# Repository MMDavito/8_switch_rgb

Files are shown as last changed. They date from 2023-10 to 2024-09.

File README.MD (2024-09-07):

# Table of contents
- [Table of contents](#table-of-contents)
- [1.1 Introduction:](#11-introduction)
- [1.2 Demonstration:](#12-demonstration)
  - [1.2.1 English:](#121-english)
  - [1.2.1 Swedish:](#121-swedish)
- [2 Design and process:](#2-design-and-process)
  - [2.1 Arduino](#21-arduino)
  - [2.2 KiCad](#22-kicad)
    - [2.2.1 Schematics and details:](#221-schematics-and-details)
      - [2.2.1.1 PCB rev0](#2211-pcb-rev0)
      - [2.2.1.2 PCB rev1](#2212-pcb-rev1)
    - [2.2.2 Custom Footprint SPDT-Switch:](#222-custom-footprint-spdt-switch)
    - [2.2.3 Custom Footprint 7-segment Display:](#223-custom-footprint-7-segment-display)
  - [2.3 FreeCAD](#23-freecad)
- [3 Assembly:](#3-assembly)
  - [3.1 Assembly of frame/stand:](#31-assembly-of-framestand)
  - [3.2 Assembly/soldering of the PCB](#32-assemblysoldering-of-the-pcb)
    - [3.2.1 Resistors required:](#321-resistors-required)
    - [3.2.2 Order of assembly:](#322-order-of-assembly)
- [4 Programming and bootloading:](#4-programming-and-bootloading)
  - [4.1 Bootloading:](#41-bootloading)
  - [4.2 Programming:](#42-programming)
  - [4.3 Programming the MCU for PCB Revision 1:](#43-programming-the-mcu-for-pcb-revision-1)

________________

# 1.1 Introduction:
This project was created to teach my niece the wonders of electricity and programming.
Here is a video trying to give and project overview and explain the process that made me go from 64 bit memory board to a "space-machine":<br>
8 Switch RGB project overview and presentation (https://www.youtube.com/watch?v=f2jGDhYTRMw)

# 1.2 Demonstration: 
## 1.2.1 English:
Using Revision 0:<br>
English demonstration revision 0 (https://www.youtube.com/watch?v=hgyK7DbGRng)

## 1.2.1 Swedish:
Better quality than the english one, using PCB revision 1:
Swedish demonstration revision 1 (https://www.youtube.com/watch?v=zpn5mNTmlIY)

___________
# 2 Design and process:
## 2.1 Arduino
No real design was put in here since the issues needing solving where clearly limited and modular in its nature, the process I choose was to solve issues limited in scope and carry out experiments with components in as modular of a manner as possible.
This is how the original prototype described in the video above ended up containing 3 ATmega-328's.

This approach did however result in many .ino files and duplicate code. The decision I made was to keep all of them; this will allow me to return 5-10 years from now and realize my process of thinking and working has changed and how, maybe I will write a book or blog-post about it. 

## 2.2 KiCad
### 2.2.1 Schematics and details:
The only major differences between the two schematics are that I have a filter on the data and clock-lines in revision 1. I also relabeled the decimal-displays from order "dec-2" to "dec-0" starting from upper left corner in revision 0, to the reversed (and ISO-standard) way of counting/indexing from 0 in the upper left corner.

I also left-out the fuse and some other things in order to conserve space.
#### 2.2.1.1 PCB rev0
Will not publish Gerbers because this version should never ever be built or produced, as can be viewed in this 30 second clip:
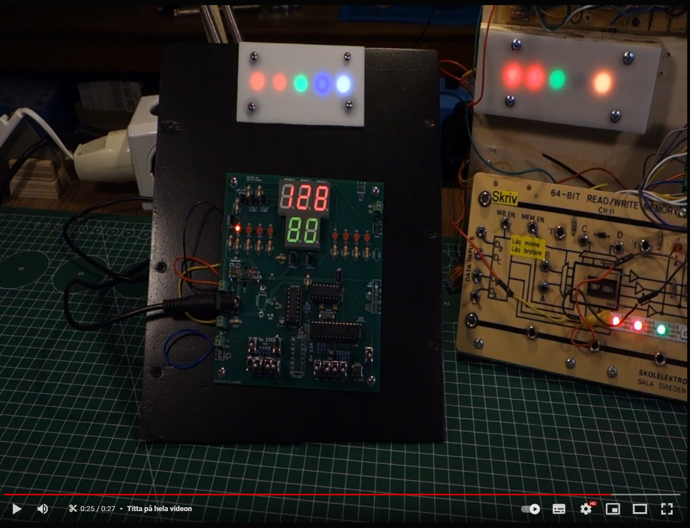
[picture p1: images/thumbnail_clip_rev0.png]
Clip showing the horror of revision 0 (https://www.youtube.com/clip/UgkxvULYqhLVdSH0bBzPMFzRGHbVHcaSfia2)

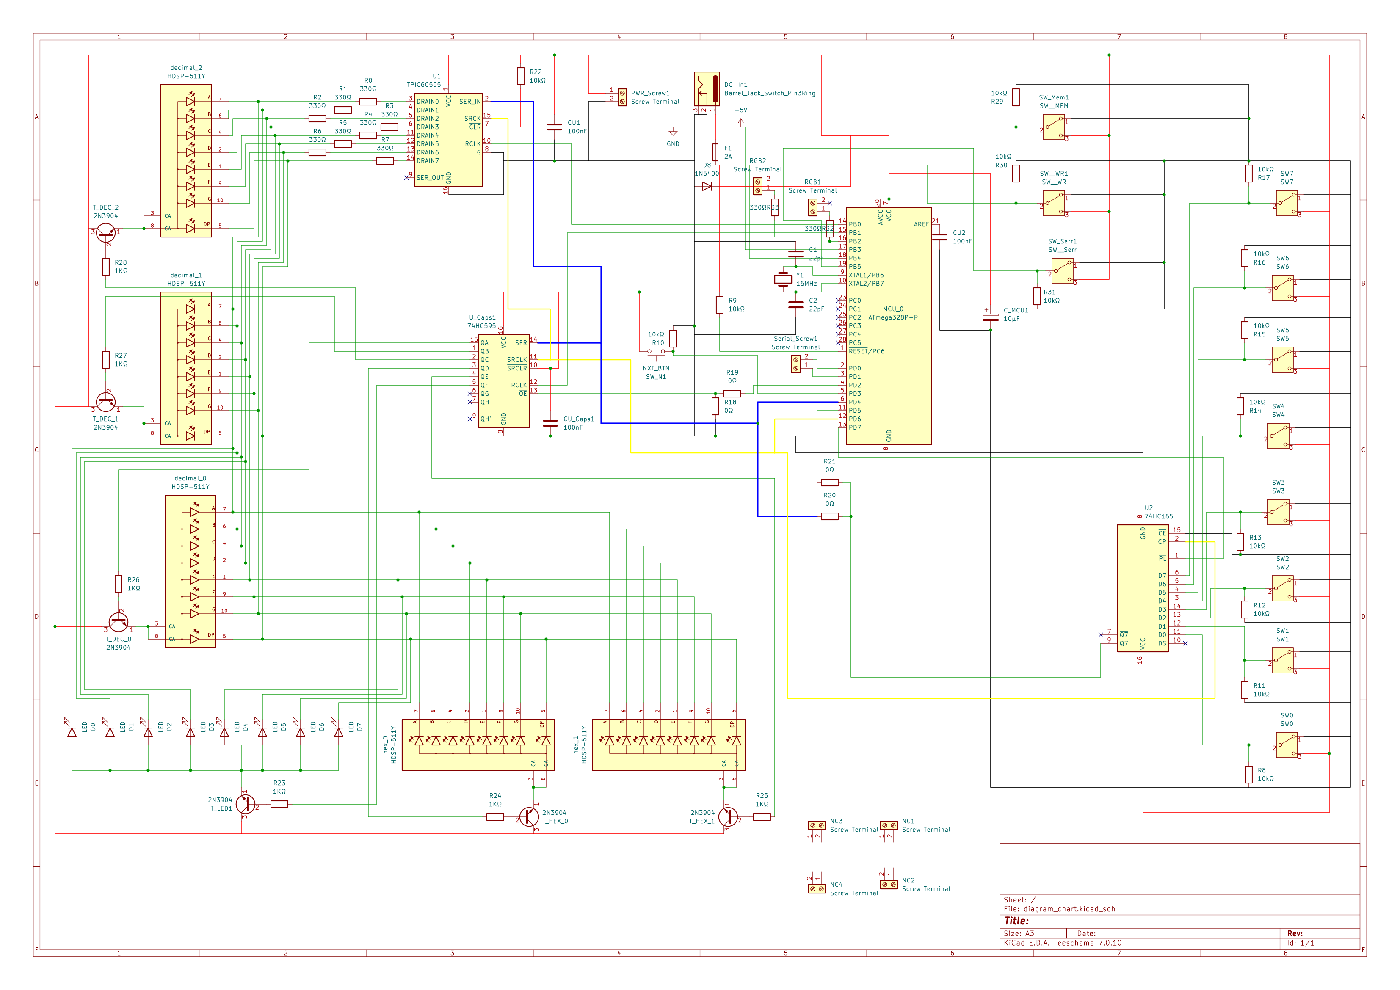
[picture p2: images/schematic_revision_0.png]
PCB revision 0 Schematic

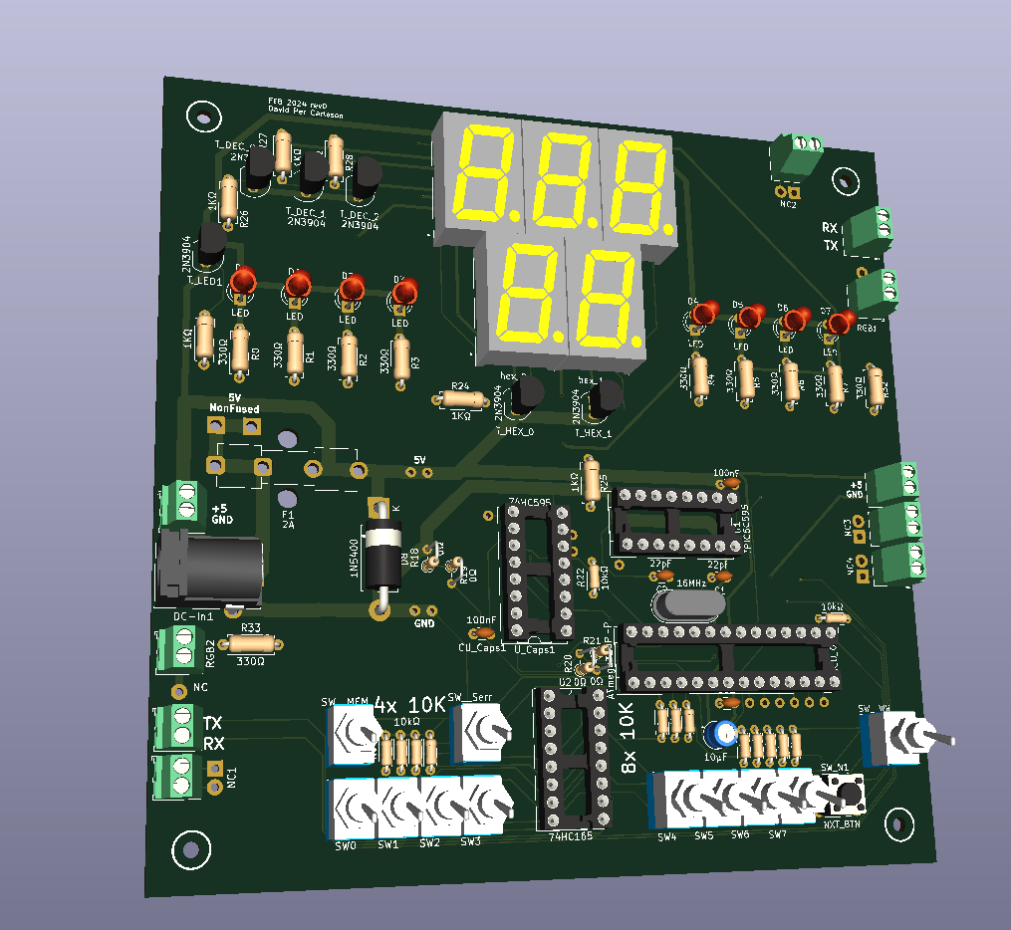
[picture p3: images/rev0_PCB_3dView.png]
PCB revision 0 PCB 3D view


#### 2.2.1.2 PCB rev1
Gerbers available for order in this directory:
https://github.com/MMDavito/8_switch_rgb/tree/master/KiCad/8_switch_rgb_pcb_revision_1/gerber_to_order
PCB revision 1 Schematic
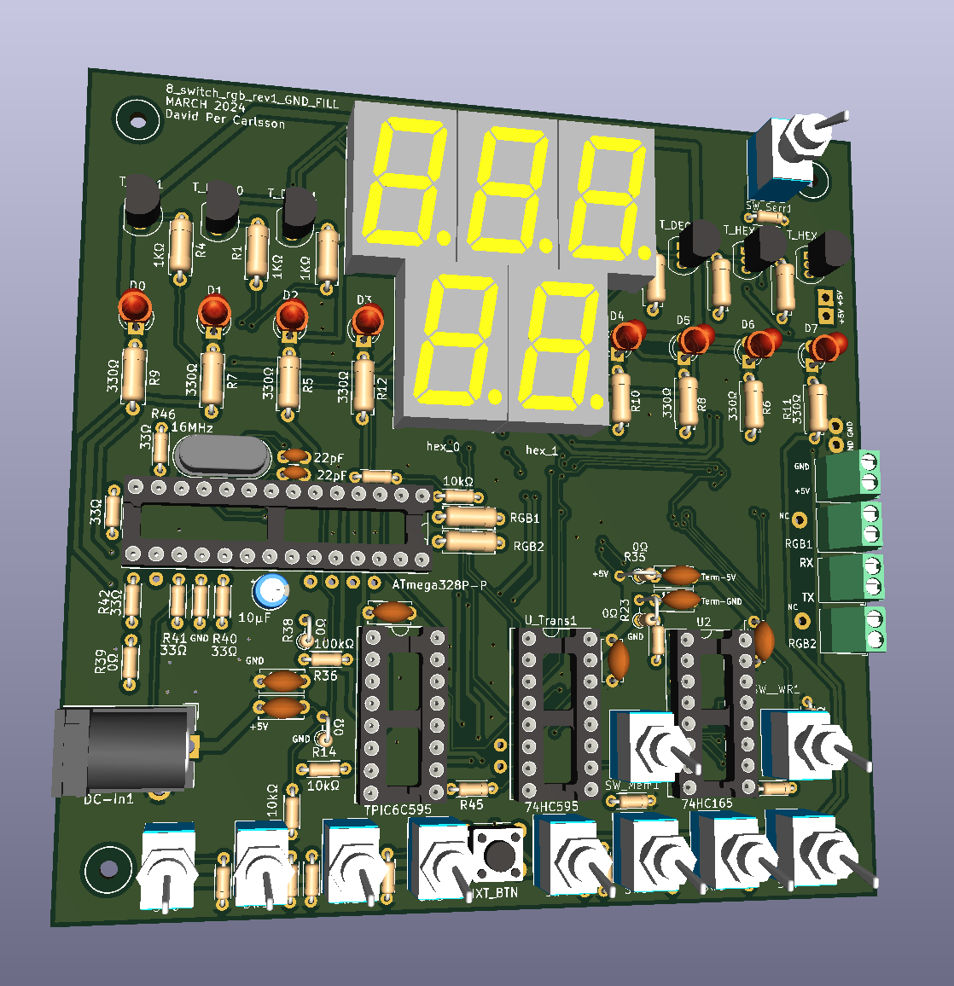
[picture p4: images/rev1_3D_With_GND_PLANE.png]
PCB revision 1 PCB 3D view

### 2.2.2 Custom Footprint SPDT-Switch:
The SPDT switch was purchased from digikey: https://www.digikey.se/sv/products/detail/adam-tech/SW-T3-2B-A-A3-S1/15284416 <br>
And later electrokit: https://www.electrokit.com/vippomkopplare-sub-miniatyr-1-pol-on-on-lodoron-smts-102

These had to be changed, since the footprints I found where for the larger 6-Amp switch. If I where to refactor the PCB I would probably make the soldering-pads 20% larger for this footprint, or even more if DRC/Design-Rules-Checker would allow it.
The custom footprint can be found here: https://github.com/MMDavito/8_switch_rgb/tree/master/KiCad/resources/Switch_Custom.pretty
### 2.2.3 Custom Footprint 7-segment Display:
The display used was a 14mm CA display purchased in RED here: https://www.electrokit.com/en/led-display-7-seg-14mm-superrod-ca <br>
And green from here: https://www.electrokit.com/en/led-display-7-seg-14mm-gron-ca

The schematics, PCB and footprint label it as a HDSP-511, which is incorrect, buying HDSP-511 would lead to buying a display too tall and wide to fit.
The edited footprint and 3D .step file can be found here:
https://github.com/MMDavito/8_switch_rgb/tree/master/KiCad/resources/HDSP-511Y
## 2.3 FreeCAD
What started as a means to an end of making it simpler to mount the PCB to a piece of plywood ended up resulting in 4 different design for holders and 3-5 different tools for making assembly simpler.

This process and designs are detailed in this readme:
https://github.com/MMDavito/8_switch_rgb/tree/master/FreeCad/README.MD
____________
# 3 Assembly:
## 3.1 Assembly of frame/stand:
More clear information and details about the 3d-printed parts found in the following video can be found in [this readme](./FreeCad/README.MD), section [3.3](./FreeCad/README.MD#33-template-to-mark-drill-holes) and [3.4](./FreeCad/README.MD#34-led-matrix-holder).<br>
Assembling stand to hold the PCB (https://youtu.be/ce8ECqhq-No)

## 3.2 Assembly/soldering of the PCB
Assembling and soldering the PCB (https://youtu.be/1DfmUe_ZbE0)

### 3.2.1 Resistors required:
__1/8 watt resistors:__
* 10kΩ * 14
* 33Ω * 8
  
__1/4 watt resistors:__
* 330Ω * 2
* 220Ω * 8
* 1kΩ * 6

### 3.2.2 Order of assembly:
1. Small resistors (1/8 watt).
2. Big resistors (1/4 watt).
3. 3mm LED:s.
4. Transistors.
5. DIL-holders.
6. Toggle switches.
7. 7-segment displays.
8. DC-plug & screw-terminals.
9. Push-button, crystal & capacitors.
_____________
# 4 Programming and bootloading:
I used this library to allow me to install bootloader and program the ATmega https://github.com/MCUdude/MiniCore
## 4.1 Bootloading:
To get the ATmega328 become programmable one needs to install a bootloader to it:<br><br>
Here is the instruction I used: https://www.instructables.com/How-to-Burn-the-Arduino-BootLoader-on-to-a-AtMega3/

Here is a alternative version: https://www.instructables.com/Burning-the-Bootloader-on-ATMega328-using-Arduino-/

In future I might adjust the board I have made from a prototype-board or order a PCB that allow me to not need a arduino UNO connected with dupont-wires to install the bootloader to the ATmega-328.

## 4.2 Programming:
Somehow I managed to program the board using diagrams and information found on this page:
https://www.instructables.com/USB-to-Serial-TTL-Adapter-to-Program-ATmega328p/

And this video: 
https://youtu.be/tiETAwkxnmw?si=Nhqw3l6RTYwrkvaB

Skimming through above links I realize that neither really shows my process of programming the MCUs, and I should probably order a PCB and create a project to detail this.

Until I find the time for creating that PCB I here bellow attach a picture comparing the breadboard vs with the soldered prototype one.

I later attached the prototype-board to a piece of plywood to make it even more robust.
Programmer breadboard vs prototype-board

## 4.3 Programming the MCU for PCB Revision 1:
Using above instructions, load this sketch onto the MCU:
https://github.com/MMDavito/8_switch_rgb/blob/master/troubleshooting_and_revision_1/2024-03-07_8_switch_rgb_pcb_rev1/8_switch_rgb_rev_1_master_control/8_switch_rgb_r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

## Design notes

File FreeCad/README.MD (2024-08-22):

# Table of contents:
- [Table of contents:](#table-of-contents)
- [1 Introduction:](#1-introduction)
- [2 Holders:](#2-holders)
  - [2.1 The legacy from pcb revision 0:](#21-the-legacy-from-pcb-revision-0)
  - [2.2 The final version for pcb revision 1](#22-the-final-version-for-pcb-revision-1)
  - [2.3 The holder to display the failings of revision 0:](#23-the-holder-to-display-the-failings-of-revision-0)
- [3 Assembly Tools:](#3-assembly-tools)
  - [3.1 Mounting Frame:](#31-mounting-frame)
  - [3.2 Resistor Lead Bender:](#32-resistor-lead-bender)
  - [3.3 Template to mark drill-holes:](#33-template-to-mark-drill-holes)
  - [3.4 LED-matrix holder:](#34-led-matrix-holder)

__________
# 1 Introduction:
Originally I made cutouts in plywood to make a holder that didn't interfere with the soldering-points. This approach proved inefficient and inaccurate.

I therefore ordered holders that allowed to mount over these holes, these where unnecessarily big, but taught me about wall-thickness and showed me one can place m3-nuts in a hexagon pocket.
The pocket in question is a hexagon constrained by a circle with the diameter 6.5mm:
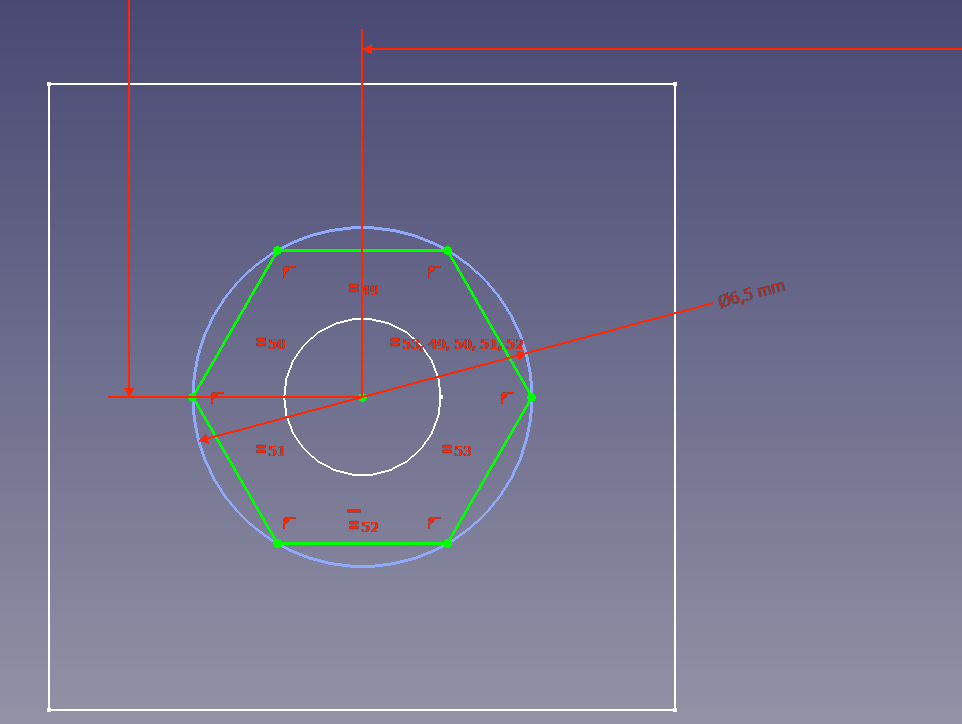
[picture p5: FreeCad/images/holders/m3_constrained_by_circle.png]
hexagon constrained by 6.5mm diameter circle


# 2 Holders:
## 2.1 The legacy from pcb revision 0:
Since the first version of the PCB (revision 0) proved to not work very well, and revision 1 being 100x100mm instead of 120x120mm in size I needed something to make the holders/stand I had built and painted useable for revision 1.

Like mentioned in the introduction the first holder was to be mounted above a hole made in the first version of the plywood holders, so it needed to have a flat mounting outside that 100x100mm hole that was there to provide clearance for the 120x120mm pcb_rev0. Therefore this versions baseplate is 150x150mm in size, which is larger than the 100x100mm needed for revision 1:
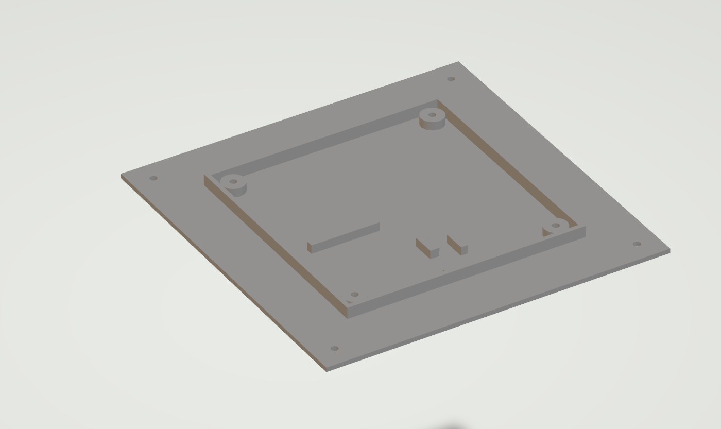
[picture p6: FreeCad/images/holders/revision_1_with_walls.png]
150mm with walls

This version also included walls and can be downloaded from [here](./holders/legacy/2-7mm_pocket_hex_1mm_bottom_1.stl).
The walls of this holder where meant to prevent a curious 3-year old from inserting a prying tool between the PCB and the surface it was mounted to.

The likelihood of such prying is minimal, but the added security that came with a minimal addition was something I deemed worthwhile.

## 2.2 The final version for pcb revision 1
Like mentioned in section 2.1 the first holder was bulky, and even though the walls added protection against prying-tools they added cost in materials.

So the version I ordered for the final version is instead meant to be mounted inside a 100x100mm hole cutout into 12mm thick plywood, this approach will make the top of the PCB remain slick against the top of the plywood, and make it seem to be part of the plywood.
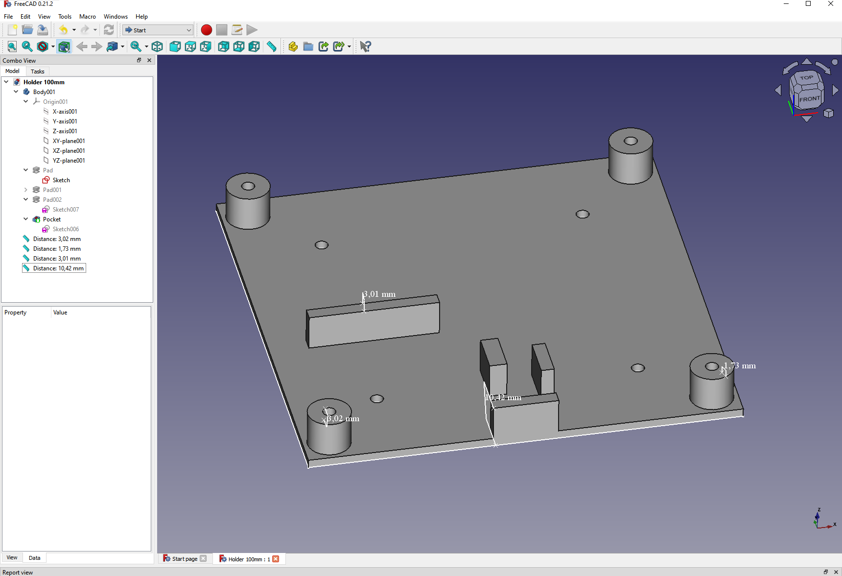
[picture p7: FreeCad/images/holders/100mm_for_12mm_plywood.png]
final version of holder, meant for use alongside 12mm plywood

The STL can be downloaded [here](./holders/2024-03-13_order/holder_100mm_12mm_plywood.stl). My use of measures and notation hint at how little I bothered to perfect my understanding of freecad; but I argue that one only needs to open [this file](./holders/Holder%20100mm.FCStd) and one can print any type of measurements at any time, this is one of the strength of opensource.

## 2.3 The holder to display the failings of revision 0:
[The STL](./holders/2024-03-13_order/holder_120mm-SquareCorners_10mm.stl) and [the CAD](./holders/legacy/holder_120mm.FCStd).<br>
Since I want to keep the failings as reminders of my ability to carry on and bring solutions, I also made a holder for the 120x120mm PCB revision 0 for mounting onto walls or holders/displays:
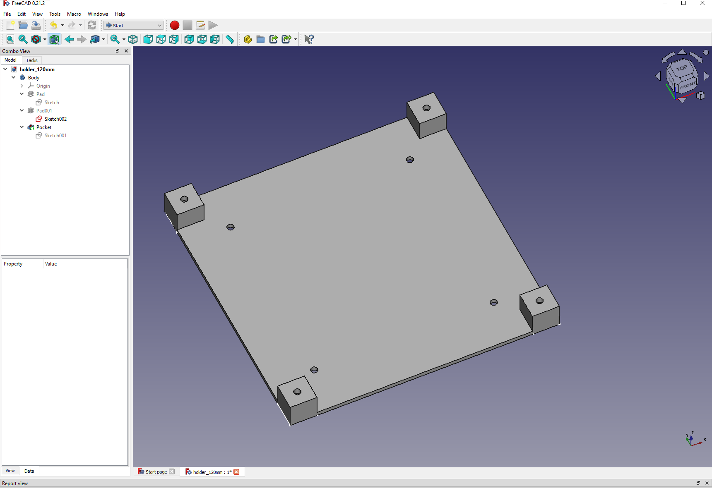
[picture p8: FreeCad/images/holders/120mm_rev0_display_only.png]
holder for 120mm revision0


# 3 Assembly Tools:

## 3.1 Mounting Frame:
[Video](https://youtu.be/1DfmUe_ZbE0?si=A3hDy3otQbanwX06&t=17)<br>
To help increasing the speed of soldering the PCB, and more importantly, to hold the LEDs and toggle-switches straight I created this frame/holder:<br>
[STL ordered](./assembling_tools/7_seg_rev1_100mm_mounting_frame.stl)
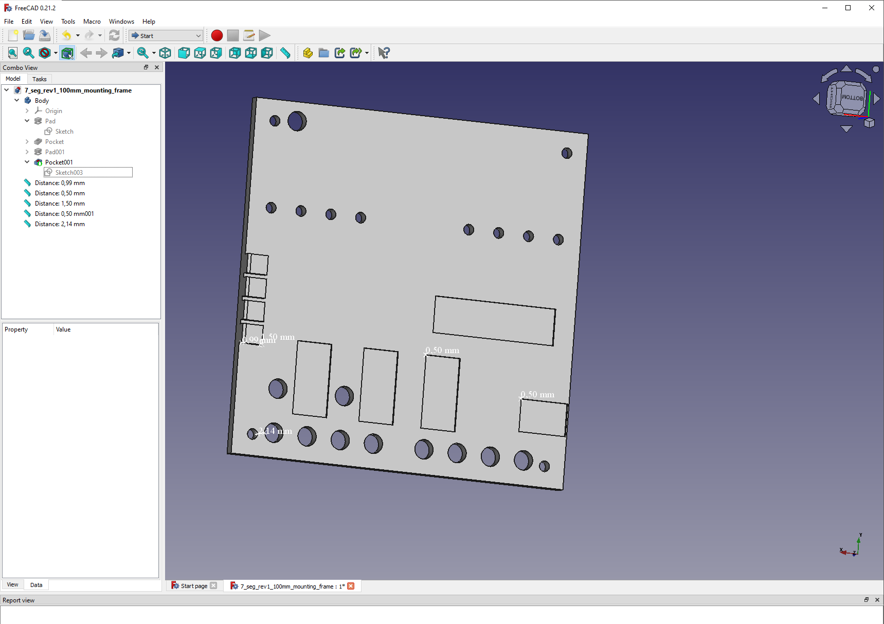
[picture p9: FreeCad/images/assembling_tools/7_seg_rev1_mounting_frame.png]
Mounting Frame


## 3.2 Resistor Lead Bender:
[Video](https://youtu.be/1DfmUe_ZbE0?si=84JAirYSgrXgPCBK&t=103)<br>
Since I use both 1/4 watt and 1/8 watt resistors with shortest minimal hole distance I am forced to insert the lead one at a time, and then use a needle nose plier to tighten them to the board.

This approach will leave unnecessarily long leads when soldering, since with the frame described in section 3.1 I no longer need them to be long to be held in place.

Instead I will cut them to length (maybe using a 3d printed part not yet created) and then bend them. But this requires me a frame to help me bend them 90 degrees. I therefore created [this Resistor Lead Bender](./assembling_tools/lead_bending/resistor_bending_tool_ver_1_rev0-BodyPocket.stl), to allow me to bend the leads of 16 resistors at a time flush to the case of the resistors:
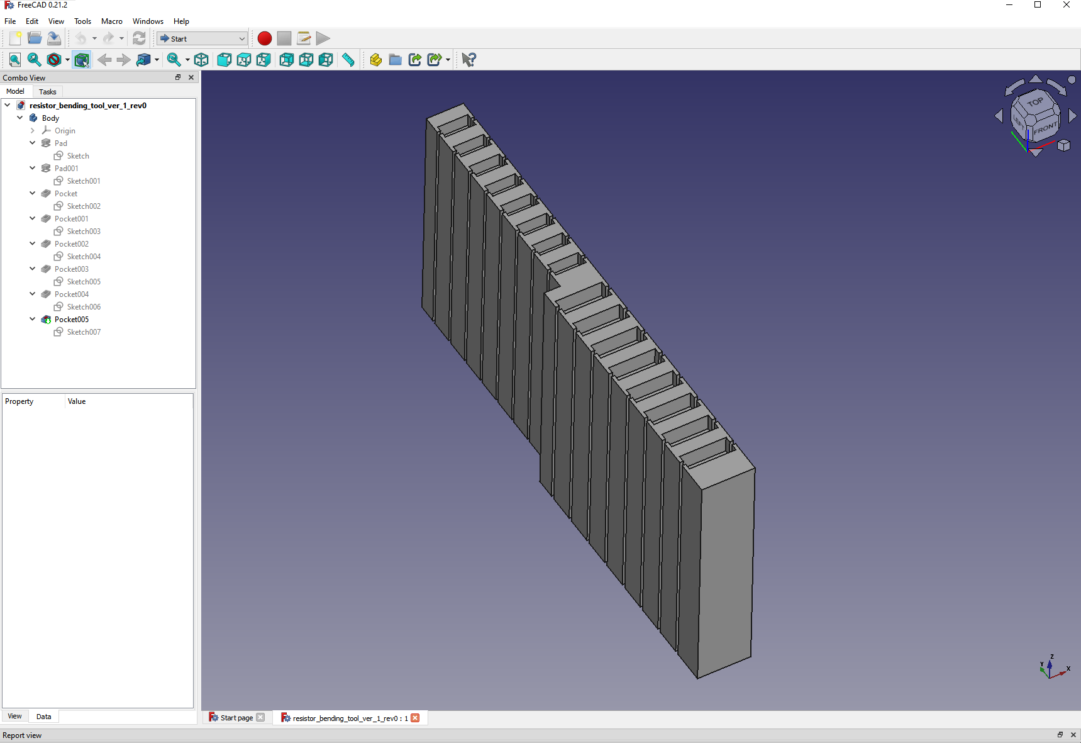
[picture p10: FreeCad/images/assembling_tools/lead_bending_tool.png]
Resistor Lead Bender

This tool is tall enough to bend the standard resistor leads without needing to cut the leads to length until one has mounted and soldered them.

## 3.3 Template to mark drill-holes:
[Video](https://youtu.be/ce8ECqhq-No?si=jgb1d80NxuUq9T-k&t=2)<br>
To make it more easy to drill holes consistent with the spacing of the LED-strip I had at hand (ws2812b 60 LED/meter), I made a matrix of 5 x 5 2 mm holes (2.5mm would been better), and 3mm holes for screws/nuts holding it in place of the previous line of holes made; allowing scaling infinitely to any direction allowing any size of LED-matrix, be that 1x15, 2x3 etc. <br>
[Freecad file](./assembling_tools/led_matrix_drill_frame.FCStd), and the [STL](./assembling_tools/led_matrix_drill_frame-BodyPad.stl)
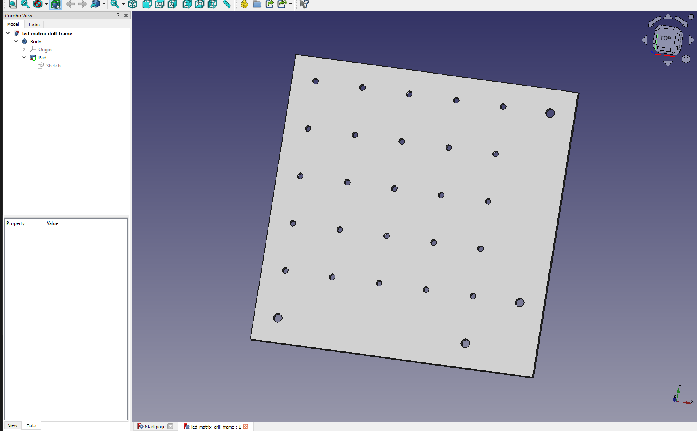
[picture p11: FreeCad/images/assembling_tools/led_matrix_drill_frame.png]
Led matrix, drill-frame


## 3.4 LED-matrix holder:
To sync with the drill holes created from the markers made using the tool from [3.3 Template to mark drill-holes](#33-template-to-mark-drill-holes) the LED matrix holder was created, to allow for attachment to a surface in a way that aligned with holes made on another surface.
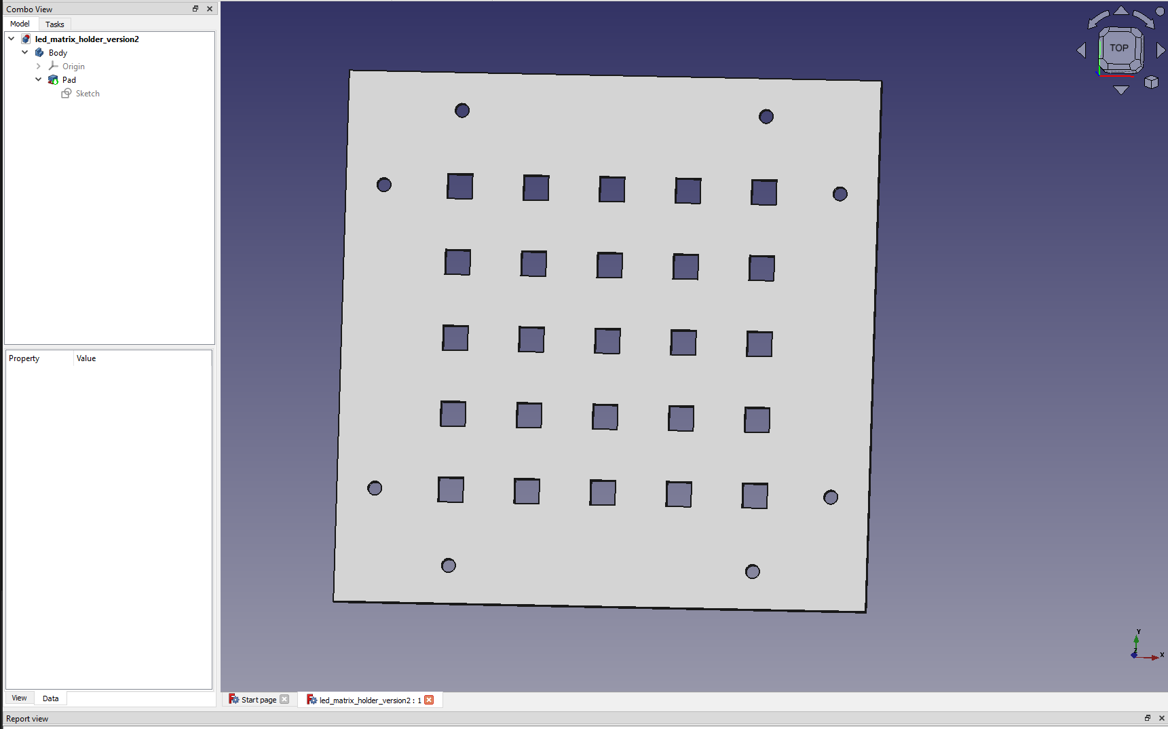
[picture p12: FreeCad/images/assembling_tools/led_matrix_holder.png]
LED-matrix Holder


Freecad file is available [here](./assembling_tools/led_matrix_holder_version2.FCStd) and the [STL here](./assembling_tools/led_matrix_holder_version2-BodyPad.stl)

Video explaining how this is used and how a vacuum-cleaner helps solving this useability can be found in this offset:ed video:
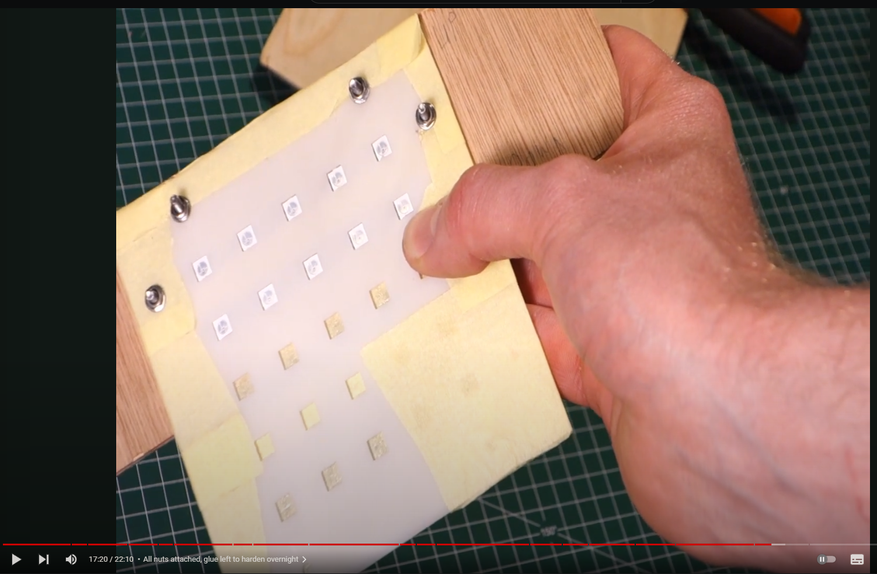
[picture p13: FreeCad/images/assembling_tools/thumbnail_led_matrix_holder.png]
"Video-segment detailing how to use the LED-matrix-holder" (https://www.youtube.com/watch?v=ce8ECqhq-No&t=713s)


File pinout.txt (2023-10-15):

1 is bottom left
8 is bottom right
9 is top right
16 is top left

1=A
2=WRen (WriteEngage)
3=MEMen
4=dA
5=outputA
6=dB
7=outputB
8=GND

9=outputC
10=dC
11=outputD
12=dD
13=D
14=C
15=B
16=VCC

how to connect for MSB == dA; LSB ==D

MSB = 
4
6
10
12

1
15
14
13
LSB

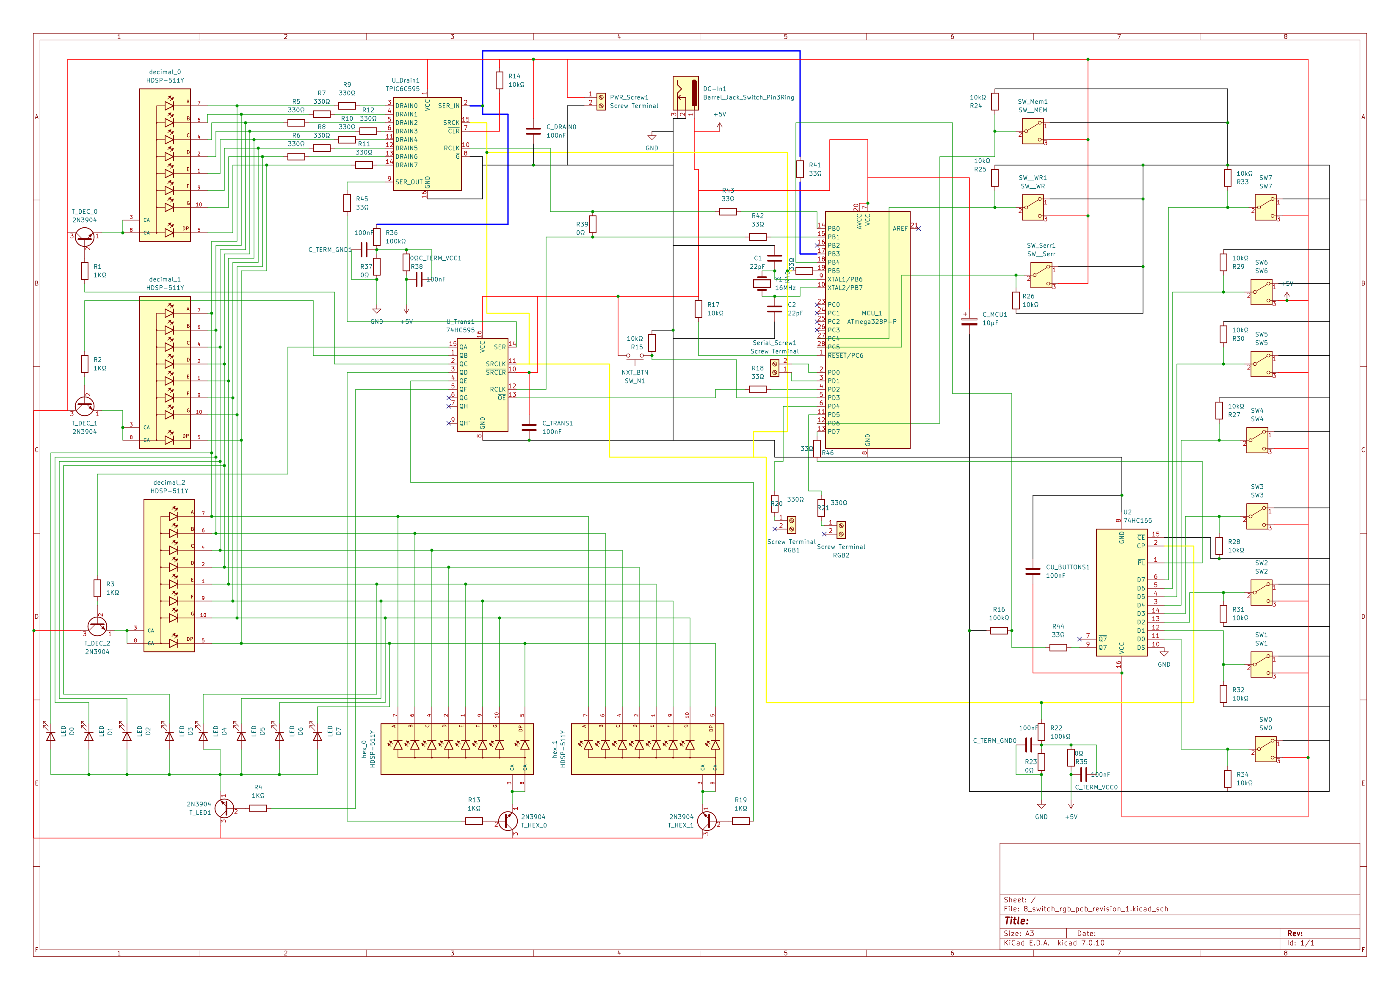
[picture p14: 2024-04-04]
images/8_switch_rgb_rev1_schematic.png

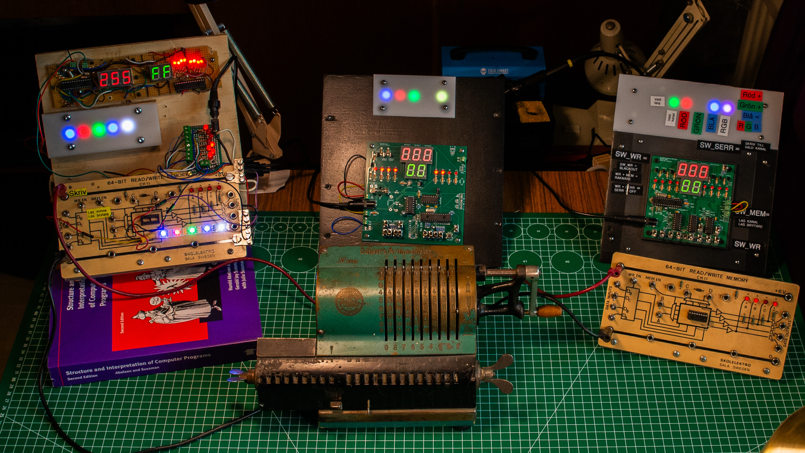
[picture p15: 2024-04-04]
images/project_overview.jpg

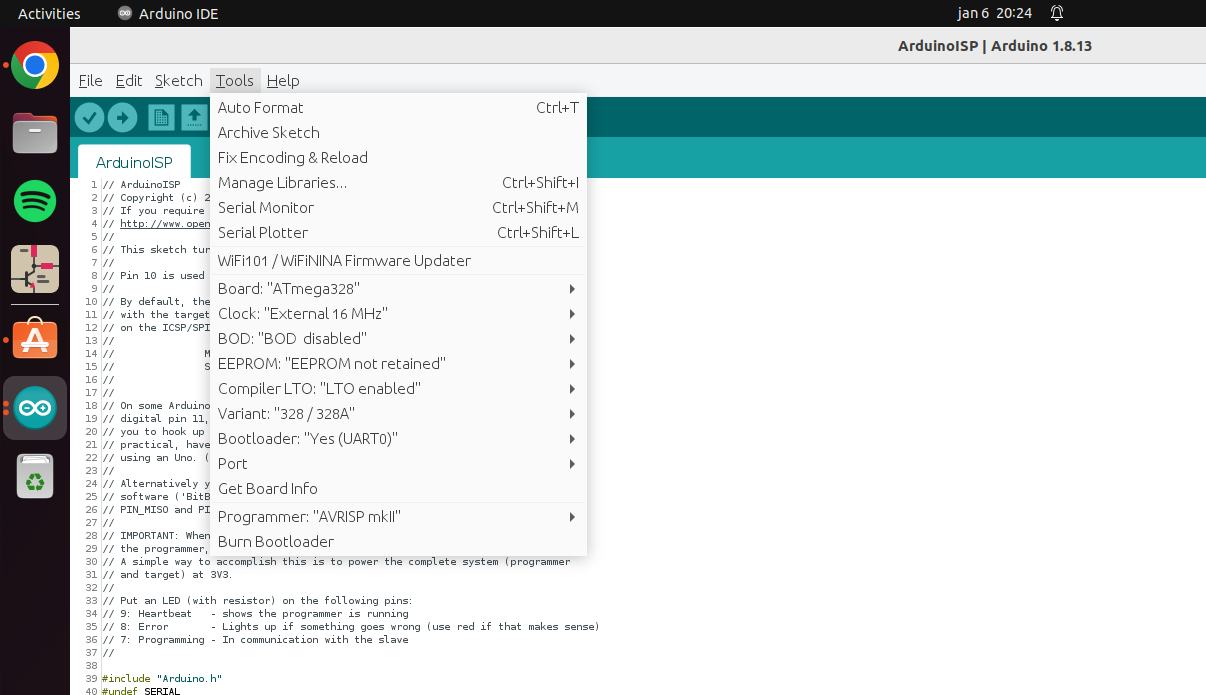
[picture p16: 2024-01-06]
atmega328p_configs_bootloader.png

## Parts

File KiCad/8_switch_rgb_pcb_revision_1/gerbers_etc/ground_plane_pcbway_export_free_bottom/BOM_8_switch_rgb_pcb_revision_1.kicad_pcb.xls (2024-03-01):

designator | quantity | value | pack | mpn | mount_type
, , , , , , , , , , , , | 13 |  |  |  | tht
C1, C2 | 2 | 22pF | C_Disc_D3.0mm_W1.6mm_P2.50mm |  | tht
CU_BUTTONS1, C_DRAIN0, C_TERM_GND0, C_TERM_GND1, C_TERM_VCC0, C_TERM_VCC1, C_TRANS1 | 7 | 100nF | C_Disc_D5.0mm_W2.5mm_P5.00mm |  | tht
C_MCU1 | 1 | 10μF | CP_Radial_D4.0mm_P2.00mm |  | tht
D0, D1, D2, D3, D4, D5, D6, D7 | 8 | LED | LED_D3.0mm |  | tht
DC-In1 | 1 | Barrel_Jack_Switch_Pin3Ring | BarrelJack_CUI_PJ-102AH_Horizontal |  | tht
MCU_1 | 1 | ATmega328P-P | DIP-28_W7.62mm_Socket |  | tht
PWR_Screw1, RGB1, RGB2, Serial_Screw1 | 4 | Screw Terminal | TerminalBlock_Phoenix_MPT-0,5-2-2.54_1x02_P2.54mm_Horizontal |  | tht
R1, R13, R19, R2, R3, R4 | 6 | 1KΩ | R_Axial_DIN0207_L6.3mm_D2.5mm_P7.62mm_Horizontal |  | tht
R10, R11, R12, R20, R21, R5, R6, R7, R8, R9 | 10 | 330Ω | R_Axial_DIN0207_L6.3mm_D2.5mm_P7.62mm_Horizontal |  | tht
R14, R15, R17, R24, R25, R26, R27, R28, R29, R30, R31, R32, R33, R34 | 14 | 10kΩ | R_Axial_DIN0204_L3.6mm_D1.6mm_P5.08mm_Horizontal |  | tht
R16, R22, R36 | 3 | 100kΩ | R_Axial_DIN0204_L3.6mm_D1.6mm_P5.08mm_Horizontal |  | tht
R18, R40, R41, R42, R43, R44, R45, R46 | 8 | 33Ω | R_Axial_DIN0204_L3.6mm_D1.6mm_P5.08mm_Horizontal |  | tht
R23, R35, R37, R38 | 4 | 0Ω | R_Axial_DIN0204_L3.6mm_D1.6mm_P2.54mm_Vertical |  | tht
R39 | 1 | 0Ω | R_Axial_DIN0204_L3.6mm_D1.6mm_P5.08mm_Horizontal |  | tht
SW0 | 1 | SW0 | SW_Toggle_Small |  | tht
SW1 | 1 | SW1 | SW_Toggle_Small |  | tht
SW2 | 1 | SW2 | SW_Toggle_Small |  | tht
SW3 | 1 | SW3 | SW_Toggle_Small |  | tht
SW4 | 1 | SW4 | SW_Toggle_Small |  | tht
SW5 | 1 | SW5 | SW_Toggle_Small |  | tht
SW6 | 1 | SW6 | SW_Toggle_Small |  | tht
SW7 | 1 | SW7 | SW_Toggle_Small |  | tht
SW_Mem1 | 1 | SW__MEM | SW_Toggle_Small |  | tht
SW_N1 | 1 | NXT_BTN | SW_PUSH_6mm_H5mm |  | tht
SW_Serr1 | 1 | SW__Serr | SW_Toggle_Small |  | tht
SW__WR1 | 1 | SW__WR | SW_Toggle_Small |  | tht
T_DEC_0, T_DEC_1, T_DEC_2, T_HEX_0, T_HEX_1, T_LED1 | 6 | 2N3904 | TO-92_Inline |  | tht
U2 | 1 | 74HC165 | DIP-16_W7.62mm_Socket |  | tht
U_Drain1 | 1 | TPIC6C595 | DIP-16_W7.62mm_Socket |  | tht
U_Trans1 | 1 | 74HC595 | DIP-16_W7.62mm_Socket |  | tht
Y1 | 1 | 16MHz | Crystal_HC49-4H_Vertical |  | tht
decimal_0, decimal_1, decimal_2, hex_0, hex_1 | 5 | HDSP-511Y | LED_HDSP-511Y |  | tht

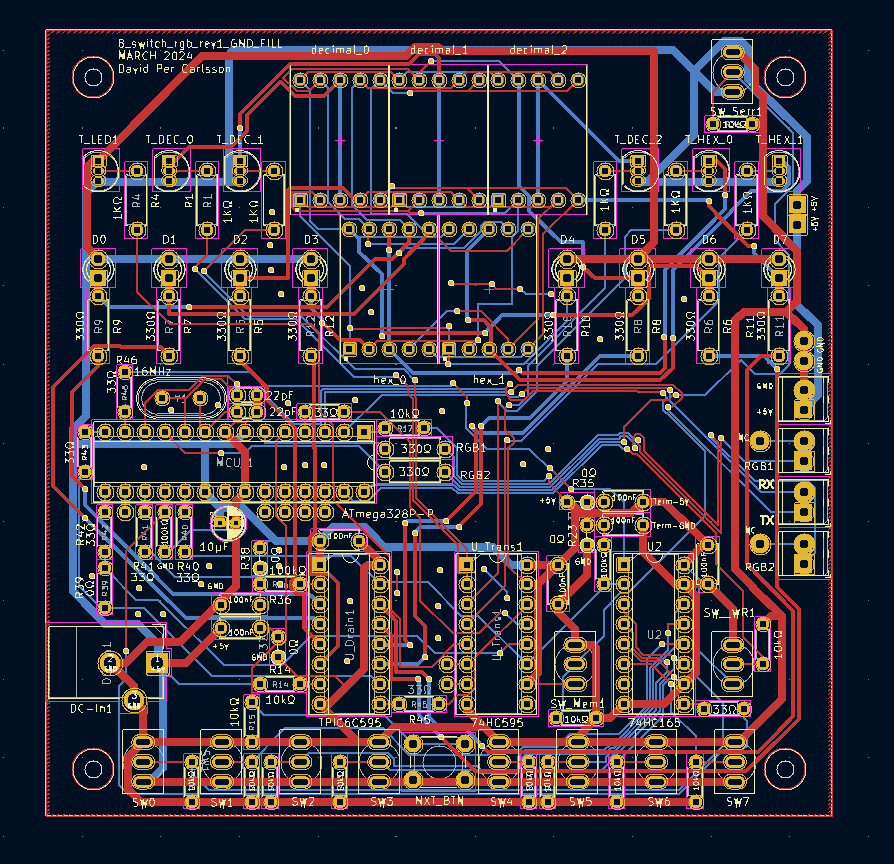
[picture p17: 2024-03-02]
KiCad/8_switch_rgb_pcb_revision_1/final_ordered_hidden_fill.png

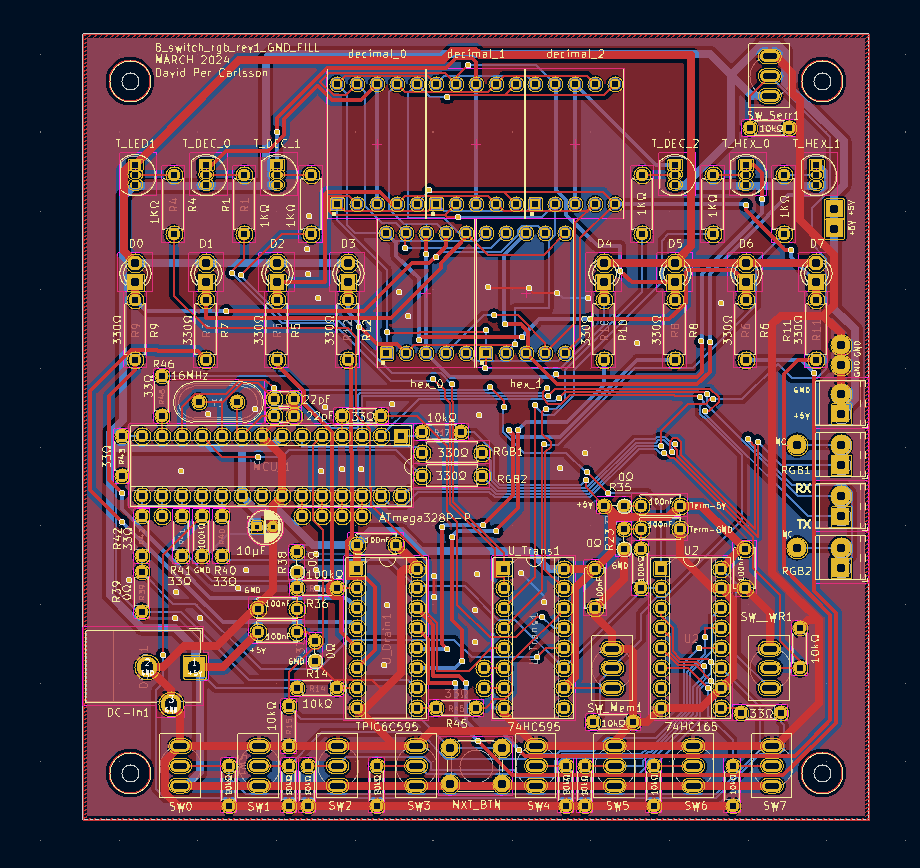
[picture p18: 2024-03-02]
KiCad/8_switch_rgb_pcb_revision_1/final_ordered_fill_displayed.png

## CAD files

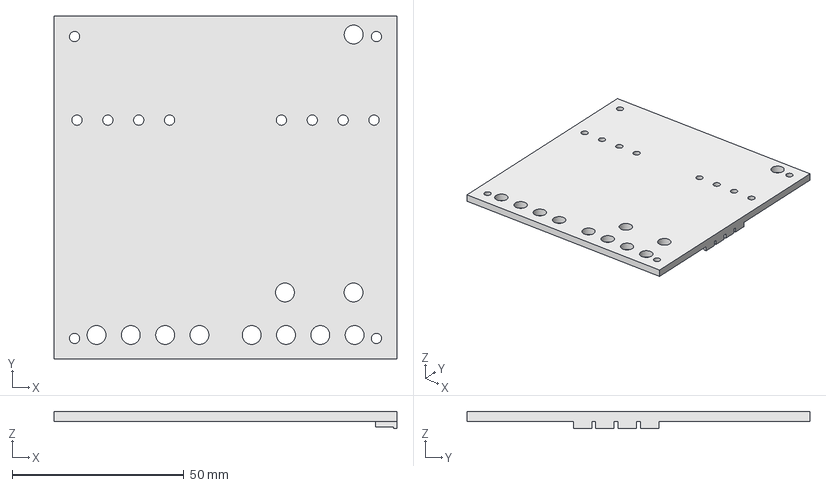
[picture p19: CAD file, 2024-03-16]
FreeCad/assembling_tools/7_seg_rev1_100mm_mounting_frame.FCStd
100.0 x 100.0 x 5.00 mm

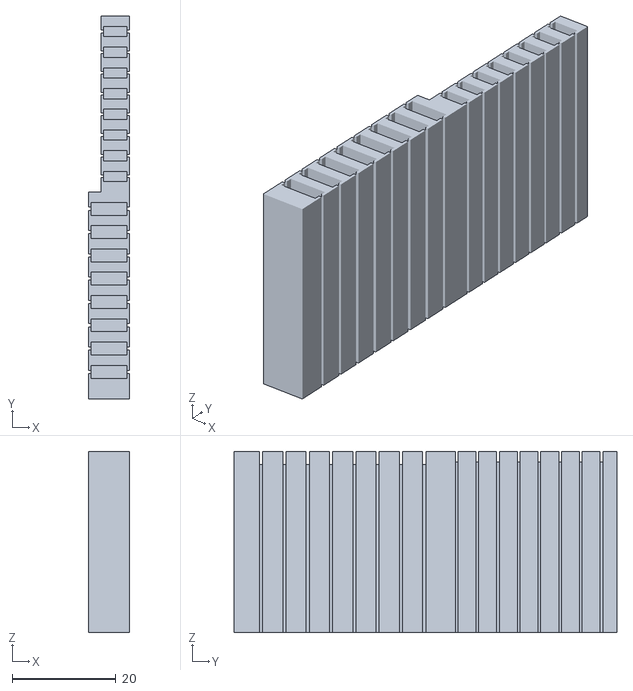
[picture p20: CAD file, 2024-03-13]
FreeCad/assembling_tools/lead_bending/resistor_bending_tool_ver_1_rev0-BodyPocket.stl
7.90 x 74.0 x 35.0

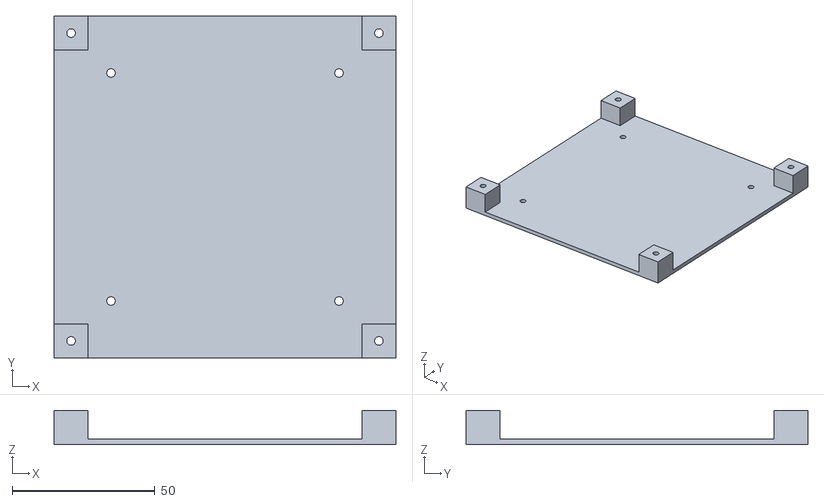
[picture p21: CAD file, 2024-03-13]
FreeCad/holders/2024-03-13_order/holder_120mm-SquareCorners_10mm.stl
120.0 x 120.0 x 12.0

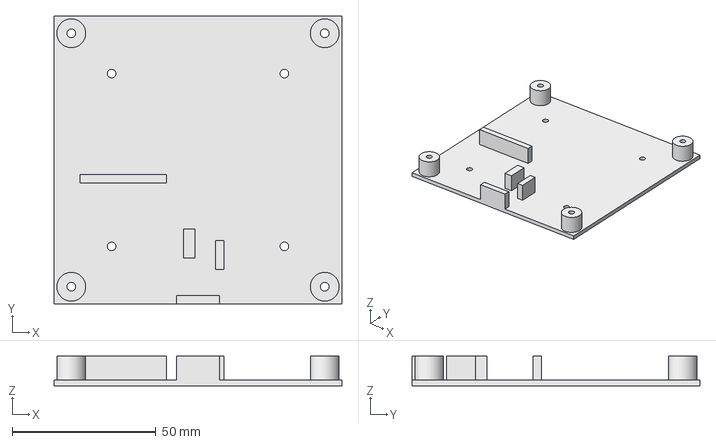
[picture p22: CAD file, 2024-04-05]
FreeCad/holders/Holder 100mm.FCStd
100.0 x 100.0 x 10.4 mm

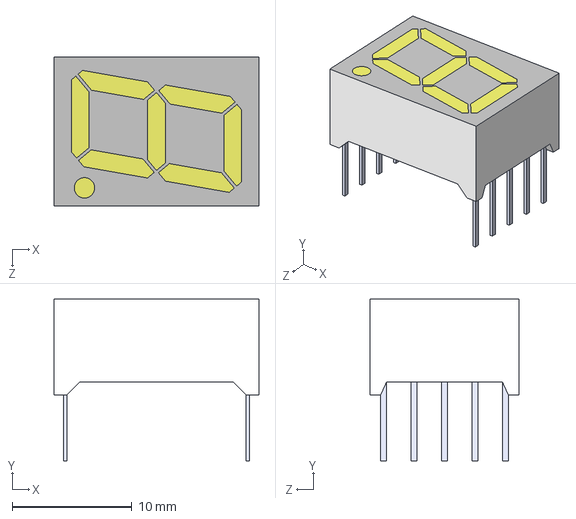
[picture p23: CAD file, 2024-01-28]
KiCad/resources/HDSP-511Y/HDSP-511Y.step
17.1 x 13.5 x 12.4 mm

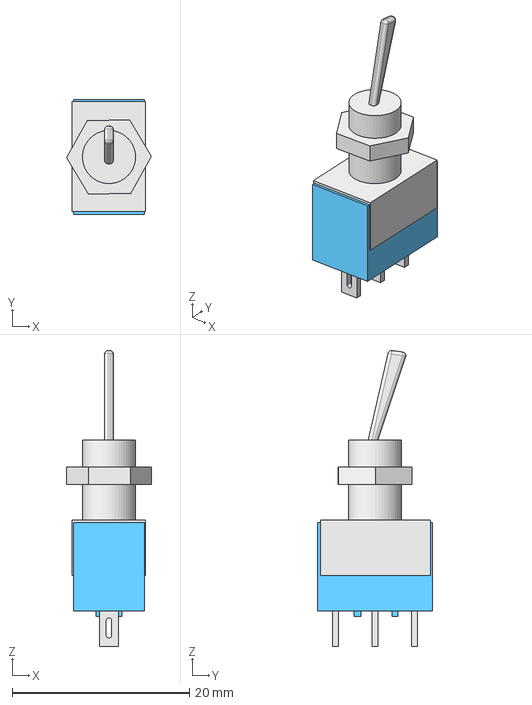
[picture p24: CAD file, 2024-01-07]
KiCad/resources/Toggle_SW_Blue_R0.step
9.58 x 13.0 x 33.4 mm
Housing
Chrome

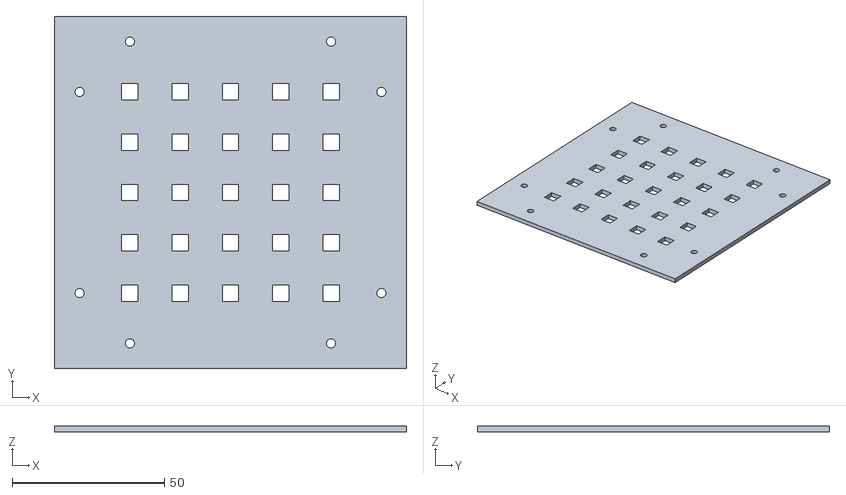
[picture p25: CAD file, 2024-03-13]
FreeCad/assembling_tools/led_matrix_holder_version2-BodyPad.stl
115.5 x 115.5 x 2.00

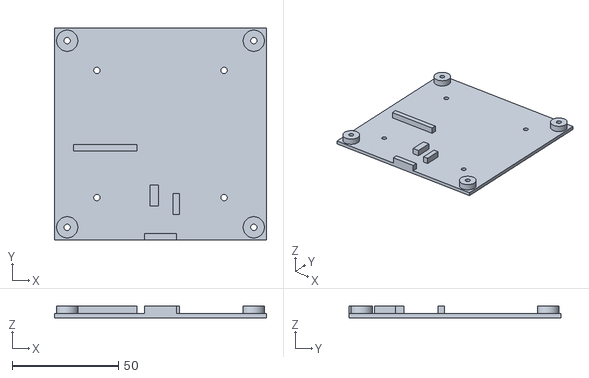
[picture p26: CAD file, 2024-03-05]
FreeCad/holders/smallest.stl
100.0 x 100.0 x 5.60

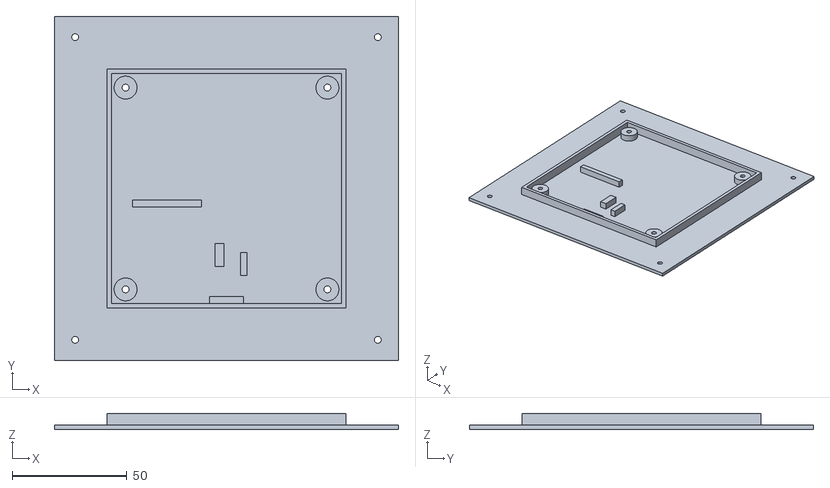
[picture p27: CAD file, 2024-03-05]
FreeCad/holders/2mm_walls.stl
150.0 x 150.0 x 7.00

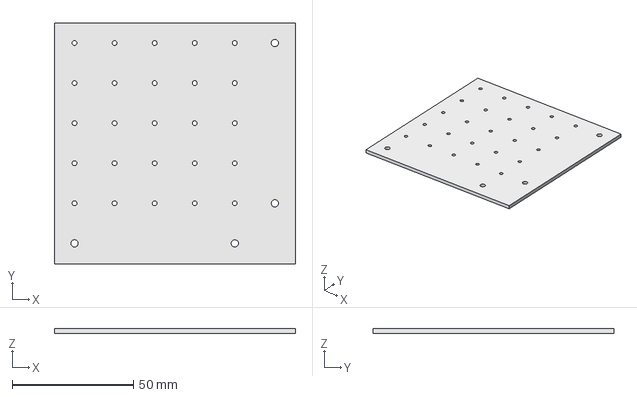
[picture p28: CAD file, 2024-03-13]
FreeCad/assembling_tools/led_matrix_drill_frame.FCStd
99.2 x 99.2 x 2.00 mm

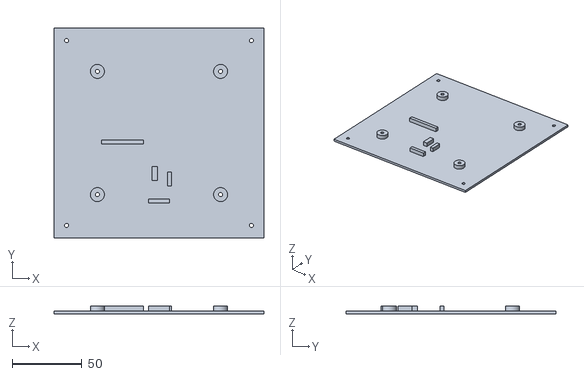
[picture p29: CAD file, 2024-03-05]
FreeCad/holders/2mm_no_edge.stl
150.0 x 150.0 x 5.60

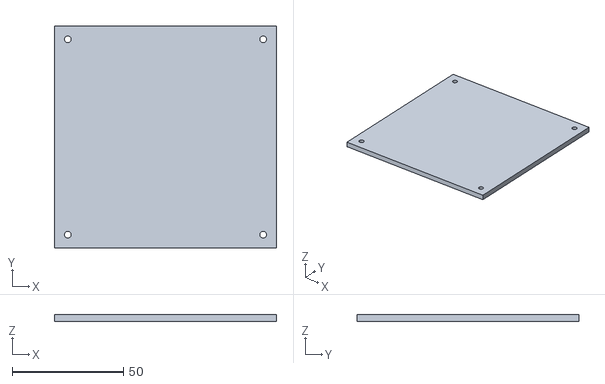
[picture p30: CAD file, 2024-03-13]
FreeCad/assembling_tools/100mm3mmthick.stl
100.0 x 100.0 x 3.00

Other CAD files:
FreeCad/assembling_tools/frame_thickness.stl
FreeCad/holders/2024-03-13_order/holder_100mm_12mm_plywood.stl
FreeCad/holders/holder_120mm.FCStd
FreeCad/assembling_tools/led_matrix_holder_version2.FCStd
FreeCad/assembling_tools/7_seg_rev1_100mm_mount_sunk_terms.stl
FreeCad/assembling_tools/led_matrix_drill_frame-BodyPad.stl
FreeCad/assembling_tools/7_seg_rev1_100mm_mounting_frame.stl
FreeCad/assembling_tools/resistor_bending_tool.FCStd
FreeCad/assembling_tools/resistor_bending_tool_ver_1_rev0.FCStd
FreeCad/holders/1mm_bottom_pads_for_button_and_mcu.stl
FreeCad/holders/2-7mm_pocket_hex_1mm_bottom.stl
FreeCad/holders/2-7mm_pocket_hex_1mm_bottom_1.stl
FreeCad/holders/5_mm_inc_pcb.stl
FreeCad/holders/6mm_screw_but_taler_pads.stl
FreeCad/holders/6mm_screw_plus_0-2mm.stl
FreeCad/holders/legacy/1mm_bottom_pads_for_button_and_mcu.stl
FreeCad/holders/legacy/2-7mm_pocket_hex_1mm_bottom.stl
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

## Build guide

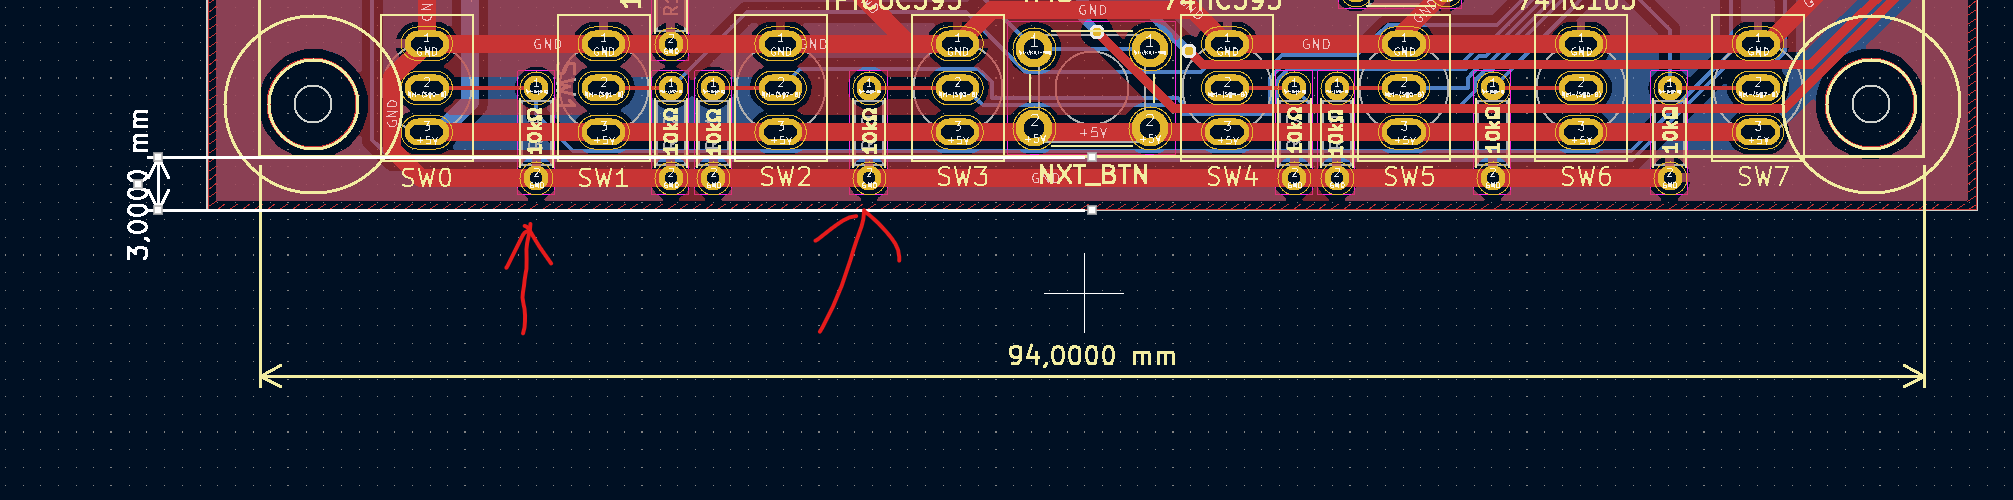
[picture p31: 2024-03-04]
FreeCad/holders/reasons_pad_makes_no_sense.png

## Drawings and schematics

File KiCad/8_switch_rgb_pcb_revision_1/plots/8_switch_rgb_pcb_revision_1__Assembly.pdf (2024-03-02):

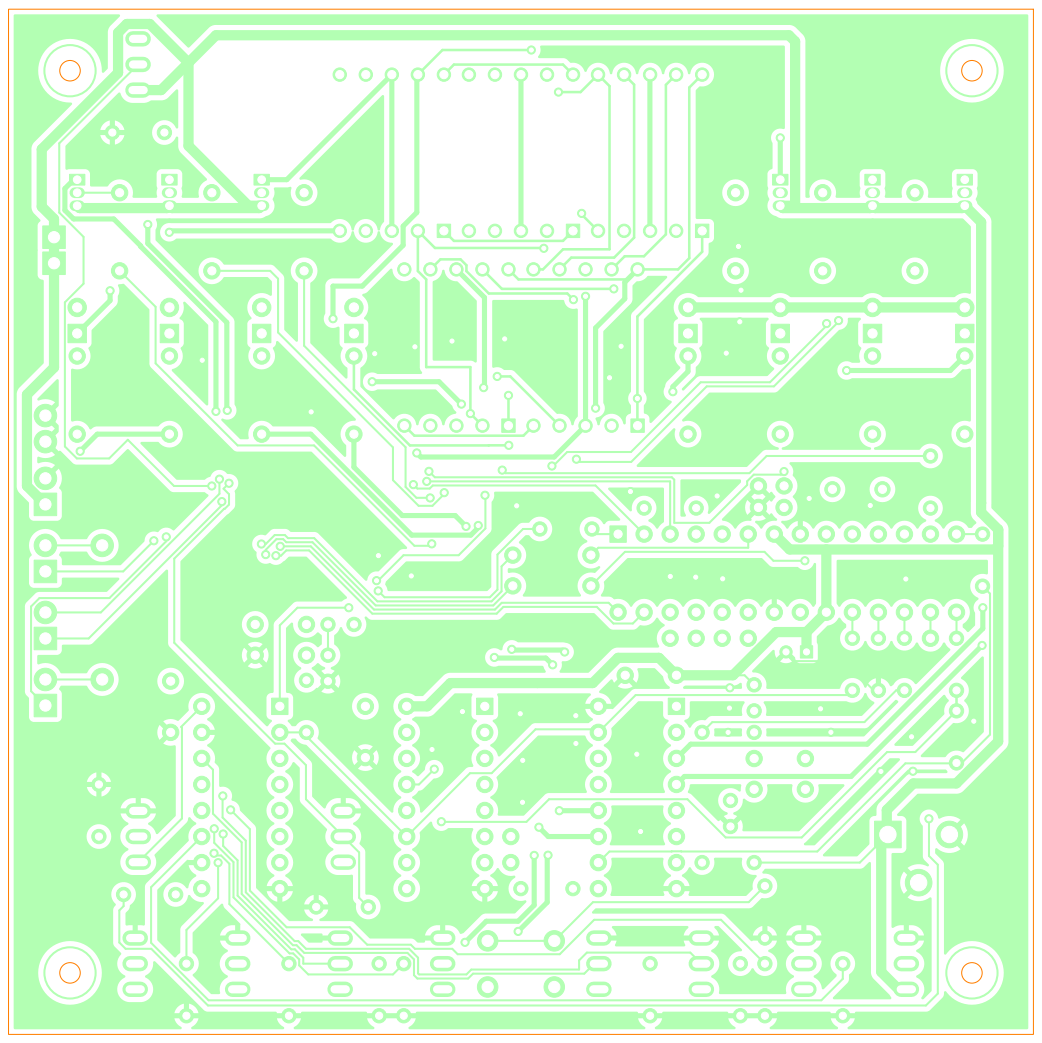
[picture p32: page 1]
D Date: KiCad; kicad; 7.0.10 Size: A4; Rev:

Id: 1/1 Title: File: 8_switch_rgb_pcb_revision_1.kicad_pcb Sheet:

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

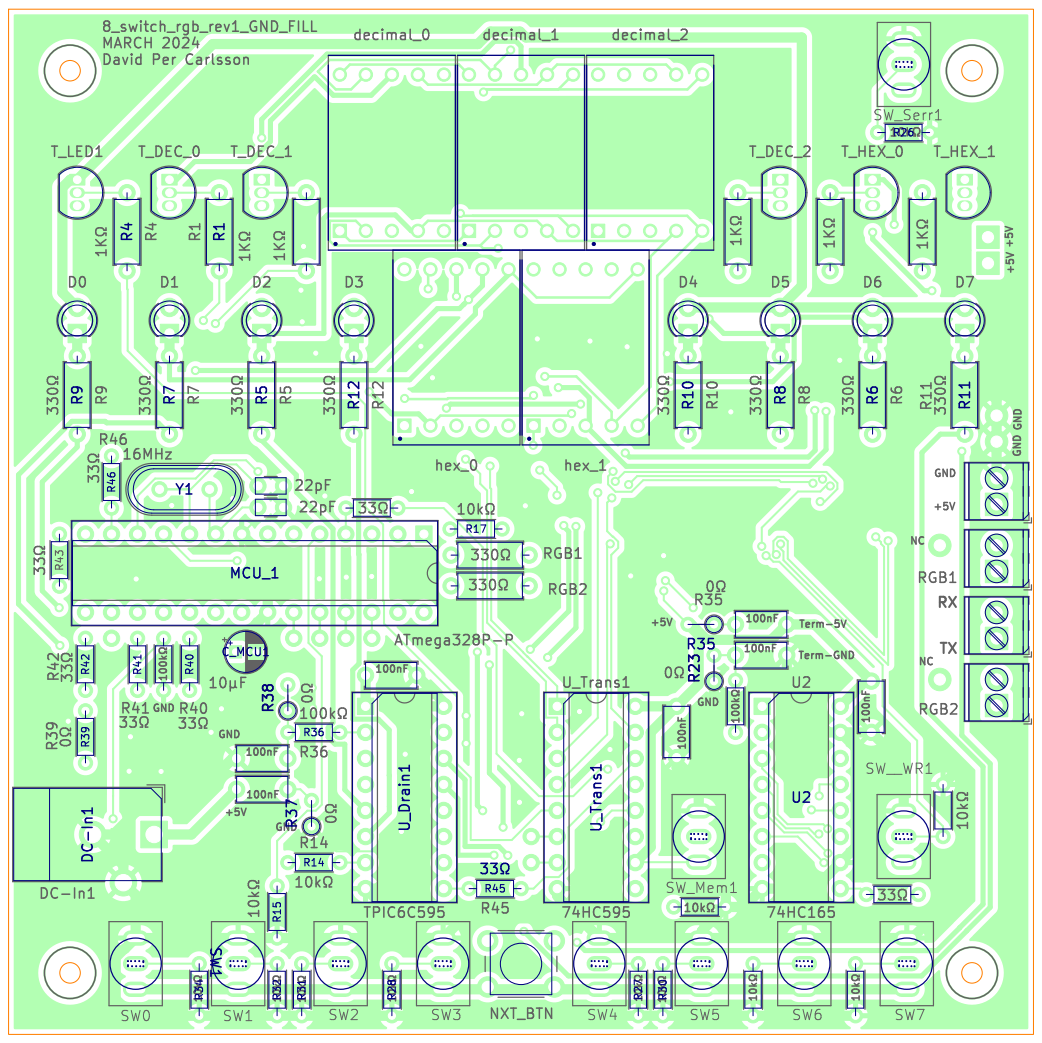
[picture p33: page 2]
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

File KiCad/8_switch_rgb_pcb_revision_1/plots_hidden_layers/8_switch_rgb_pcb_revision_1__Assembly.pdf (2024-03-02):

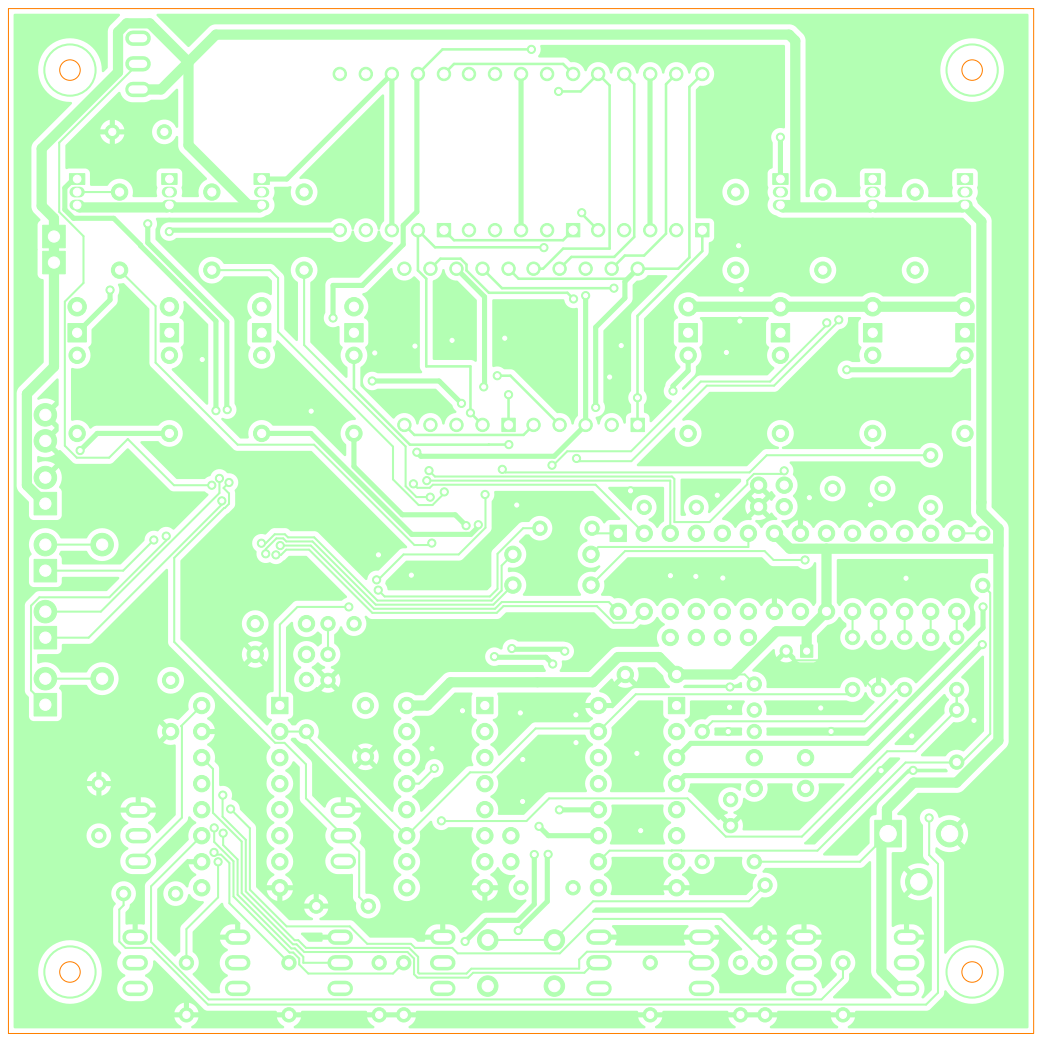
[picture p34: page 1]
F Date: KiCad; kicad; 7.0.10 Size: A4; Rev:

Id: 1/1 Title: File: 8_switch_rgb_pcb_revision_1.kicad_pcb Sheet:

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

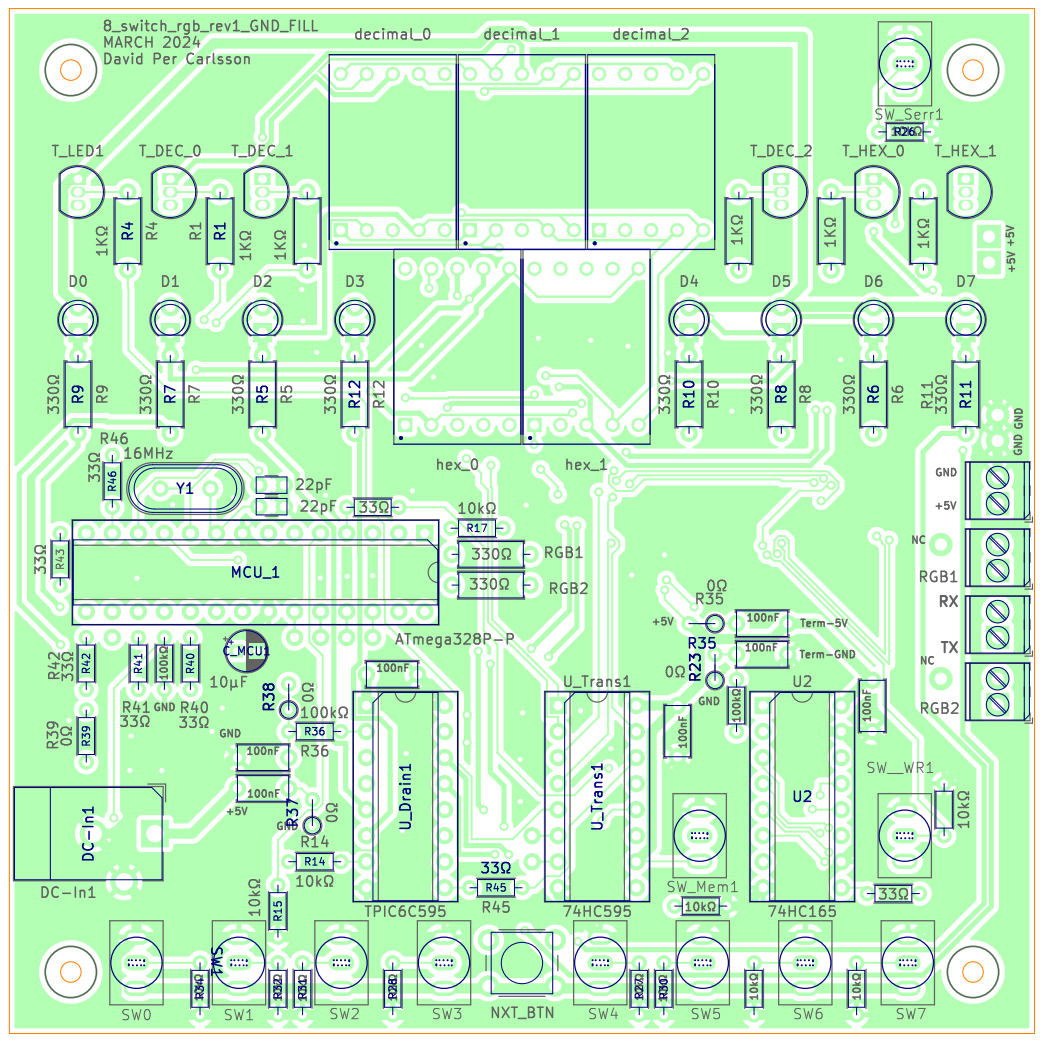
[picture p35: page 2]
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

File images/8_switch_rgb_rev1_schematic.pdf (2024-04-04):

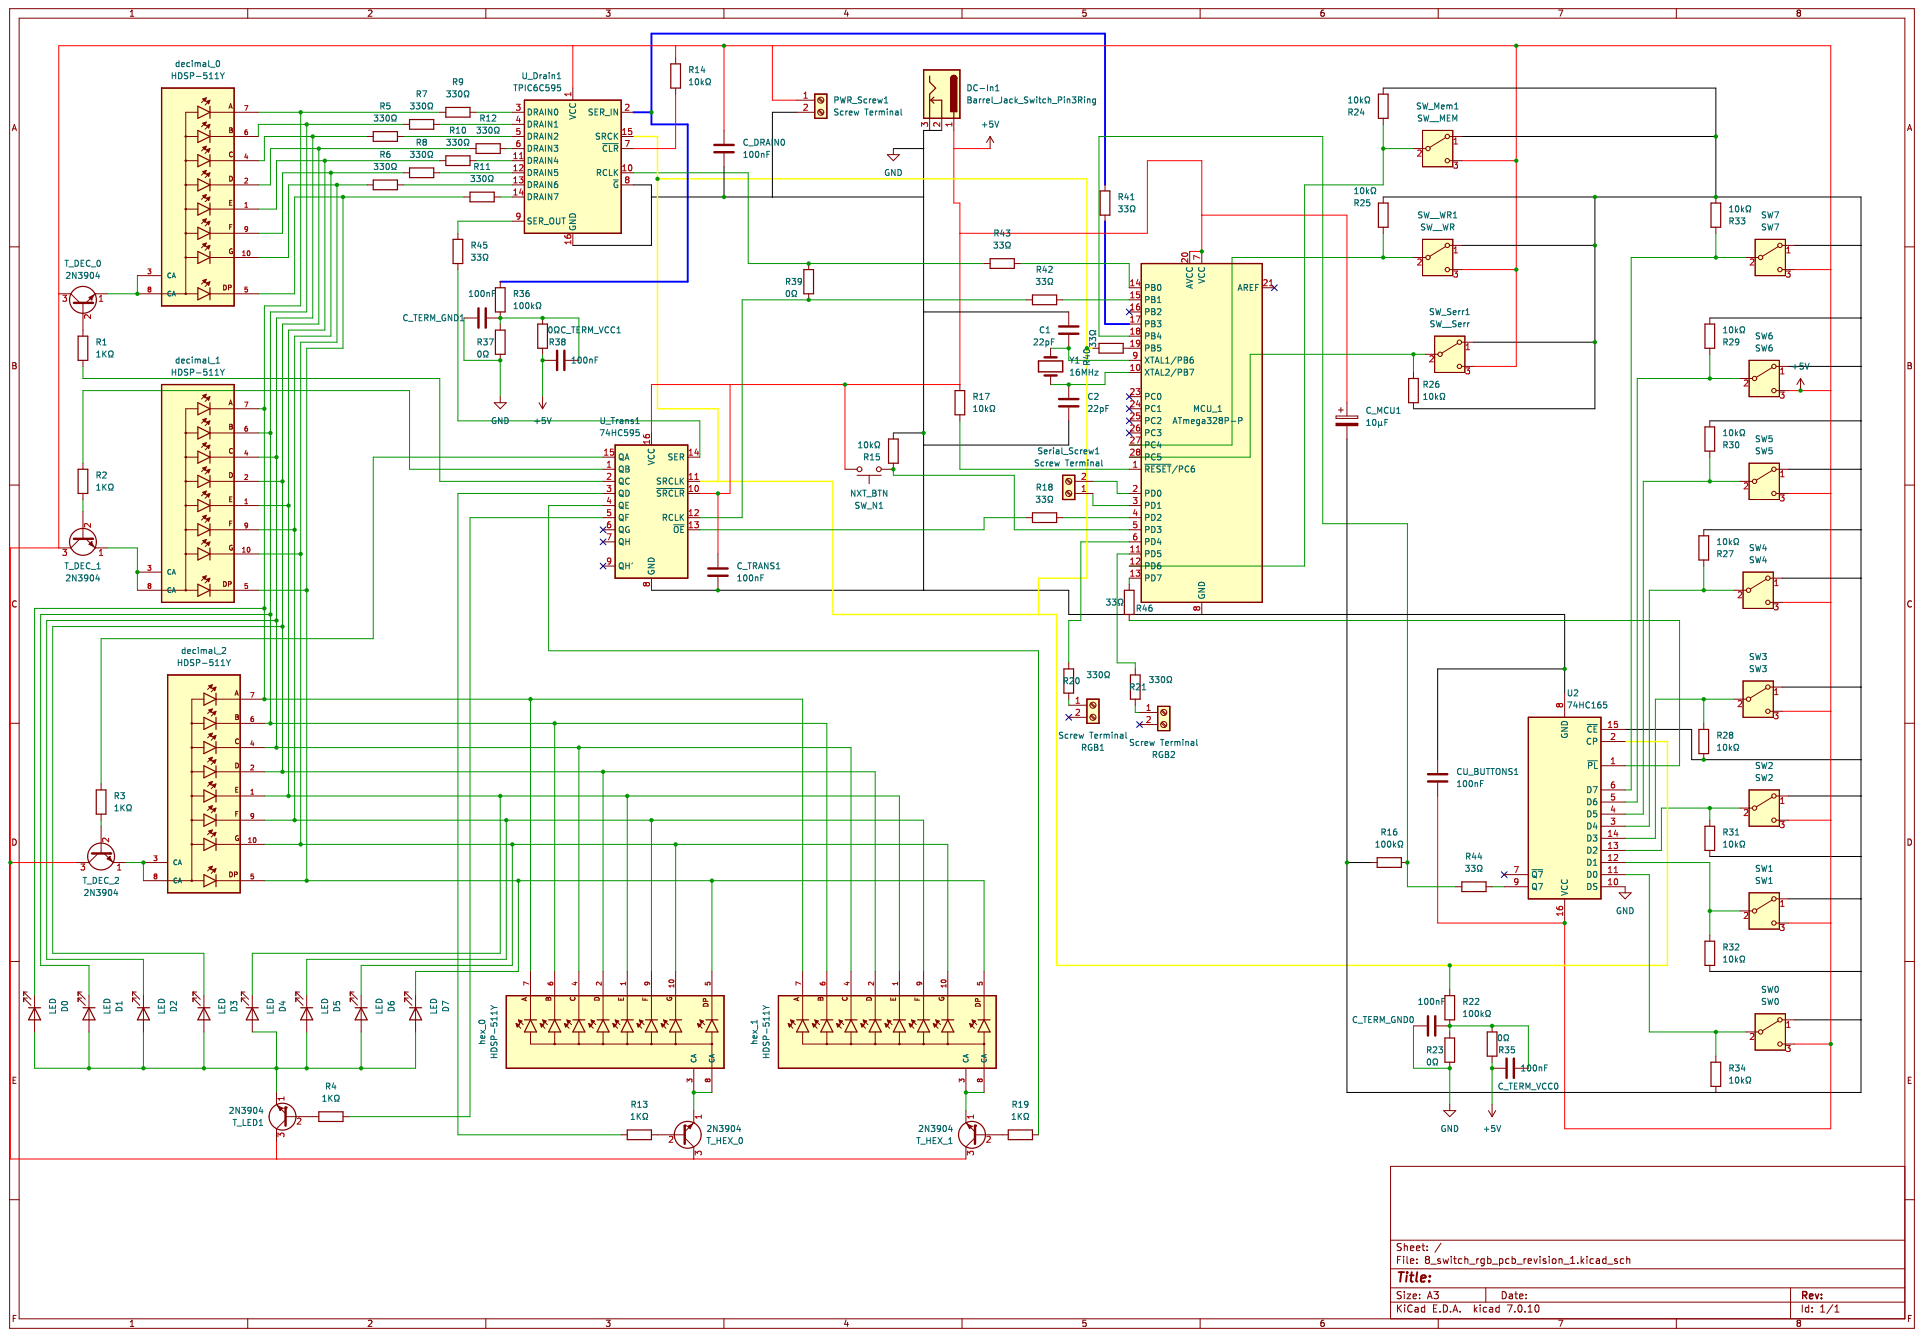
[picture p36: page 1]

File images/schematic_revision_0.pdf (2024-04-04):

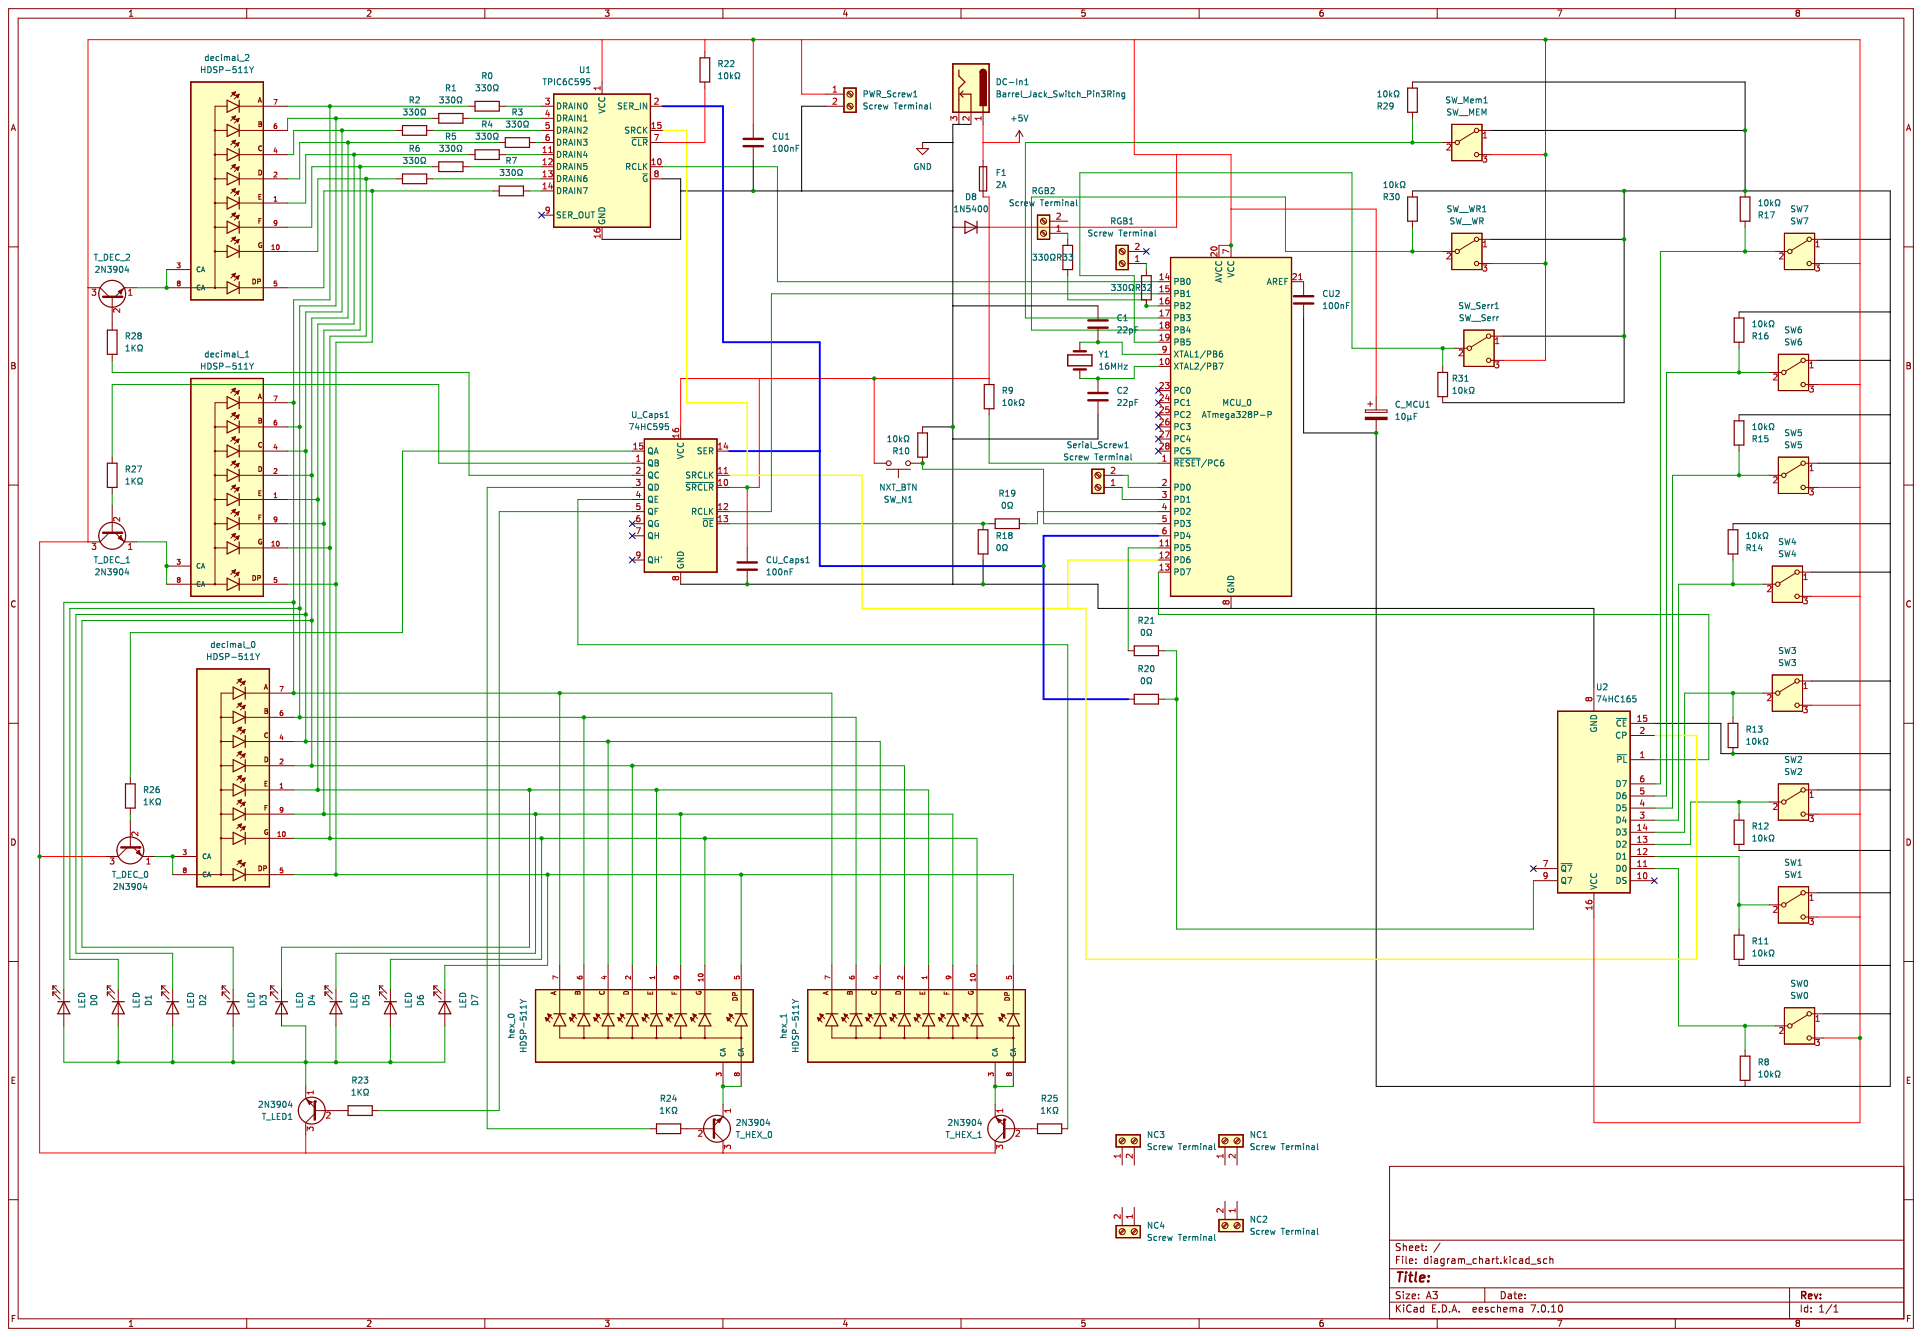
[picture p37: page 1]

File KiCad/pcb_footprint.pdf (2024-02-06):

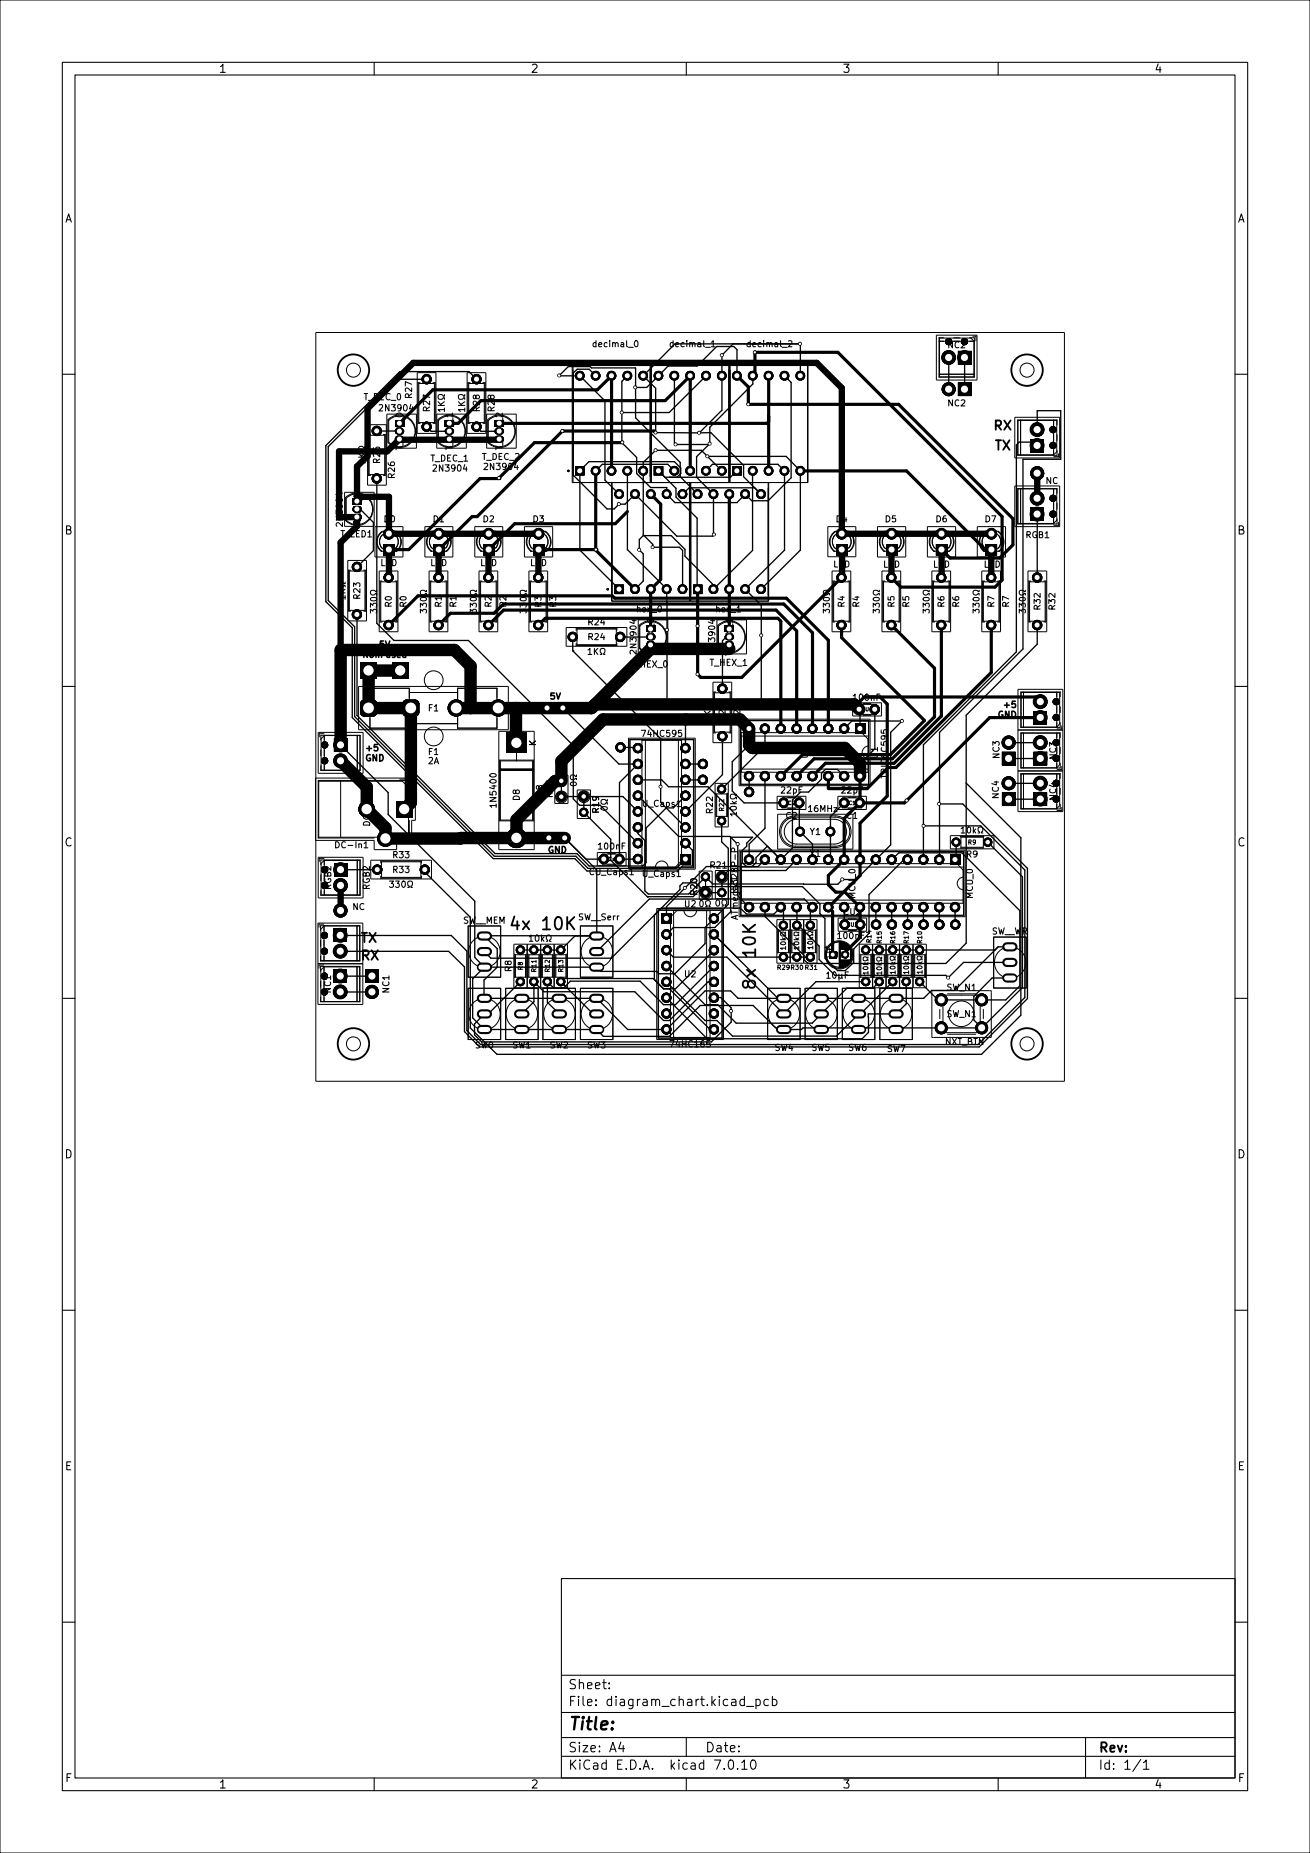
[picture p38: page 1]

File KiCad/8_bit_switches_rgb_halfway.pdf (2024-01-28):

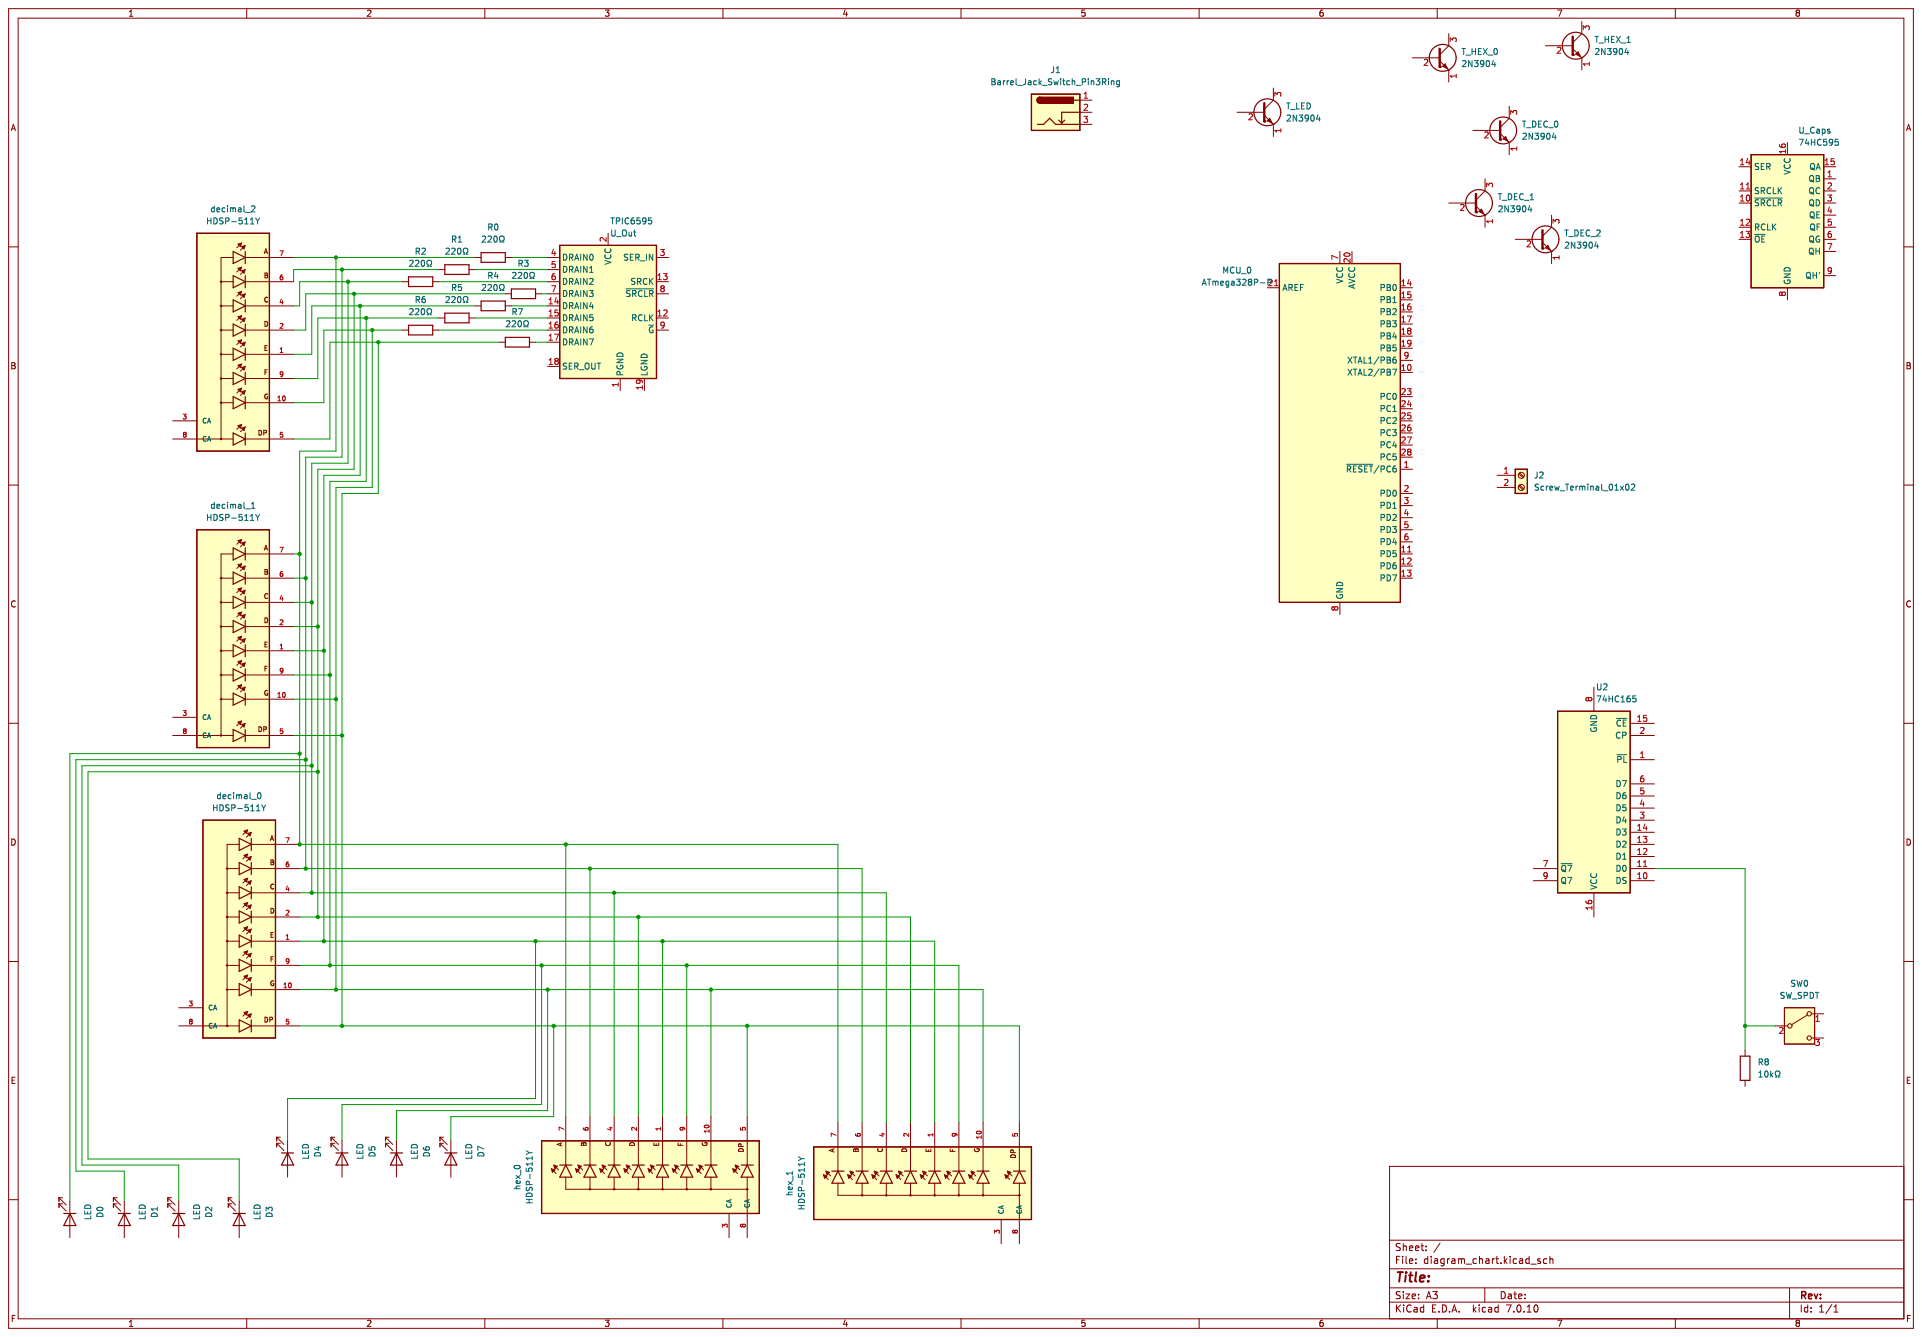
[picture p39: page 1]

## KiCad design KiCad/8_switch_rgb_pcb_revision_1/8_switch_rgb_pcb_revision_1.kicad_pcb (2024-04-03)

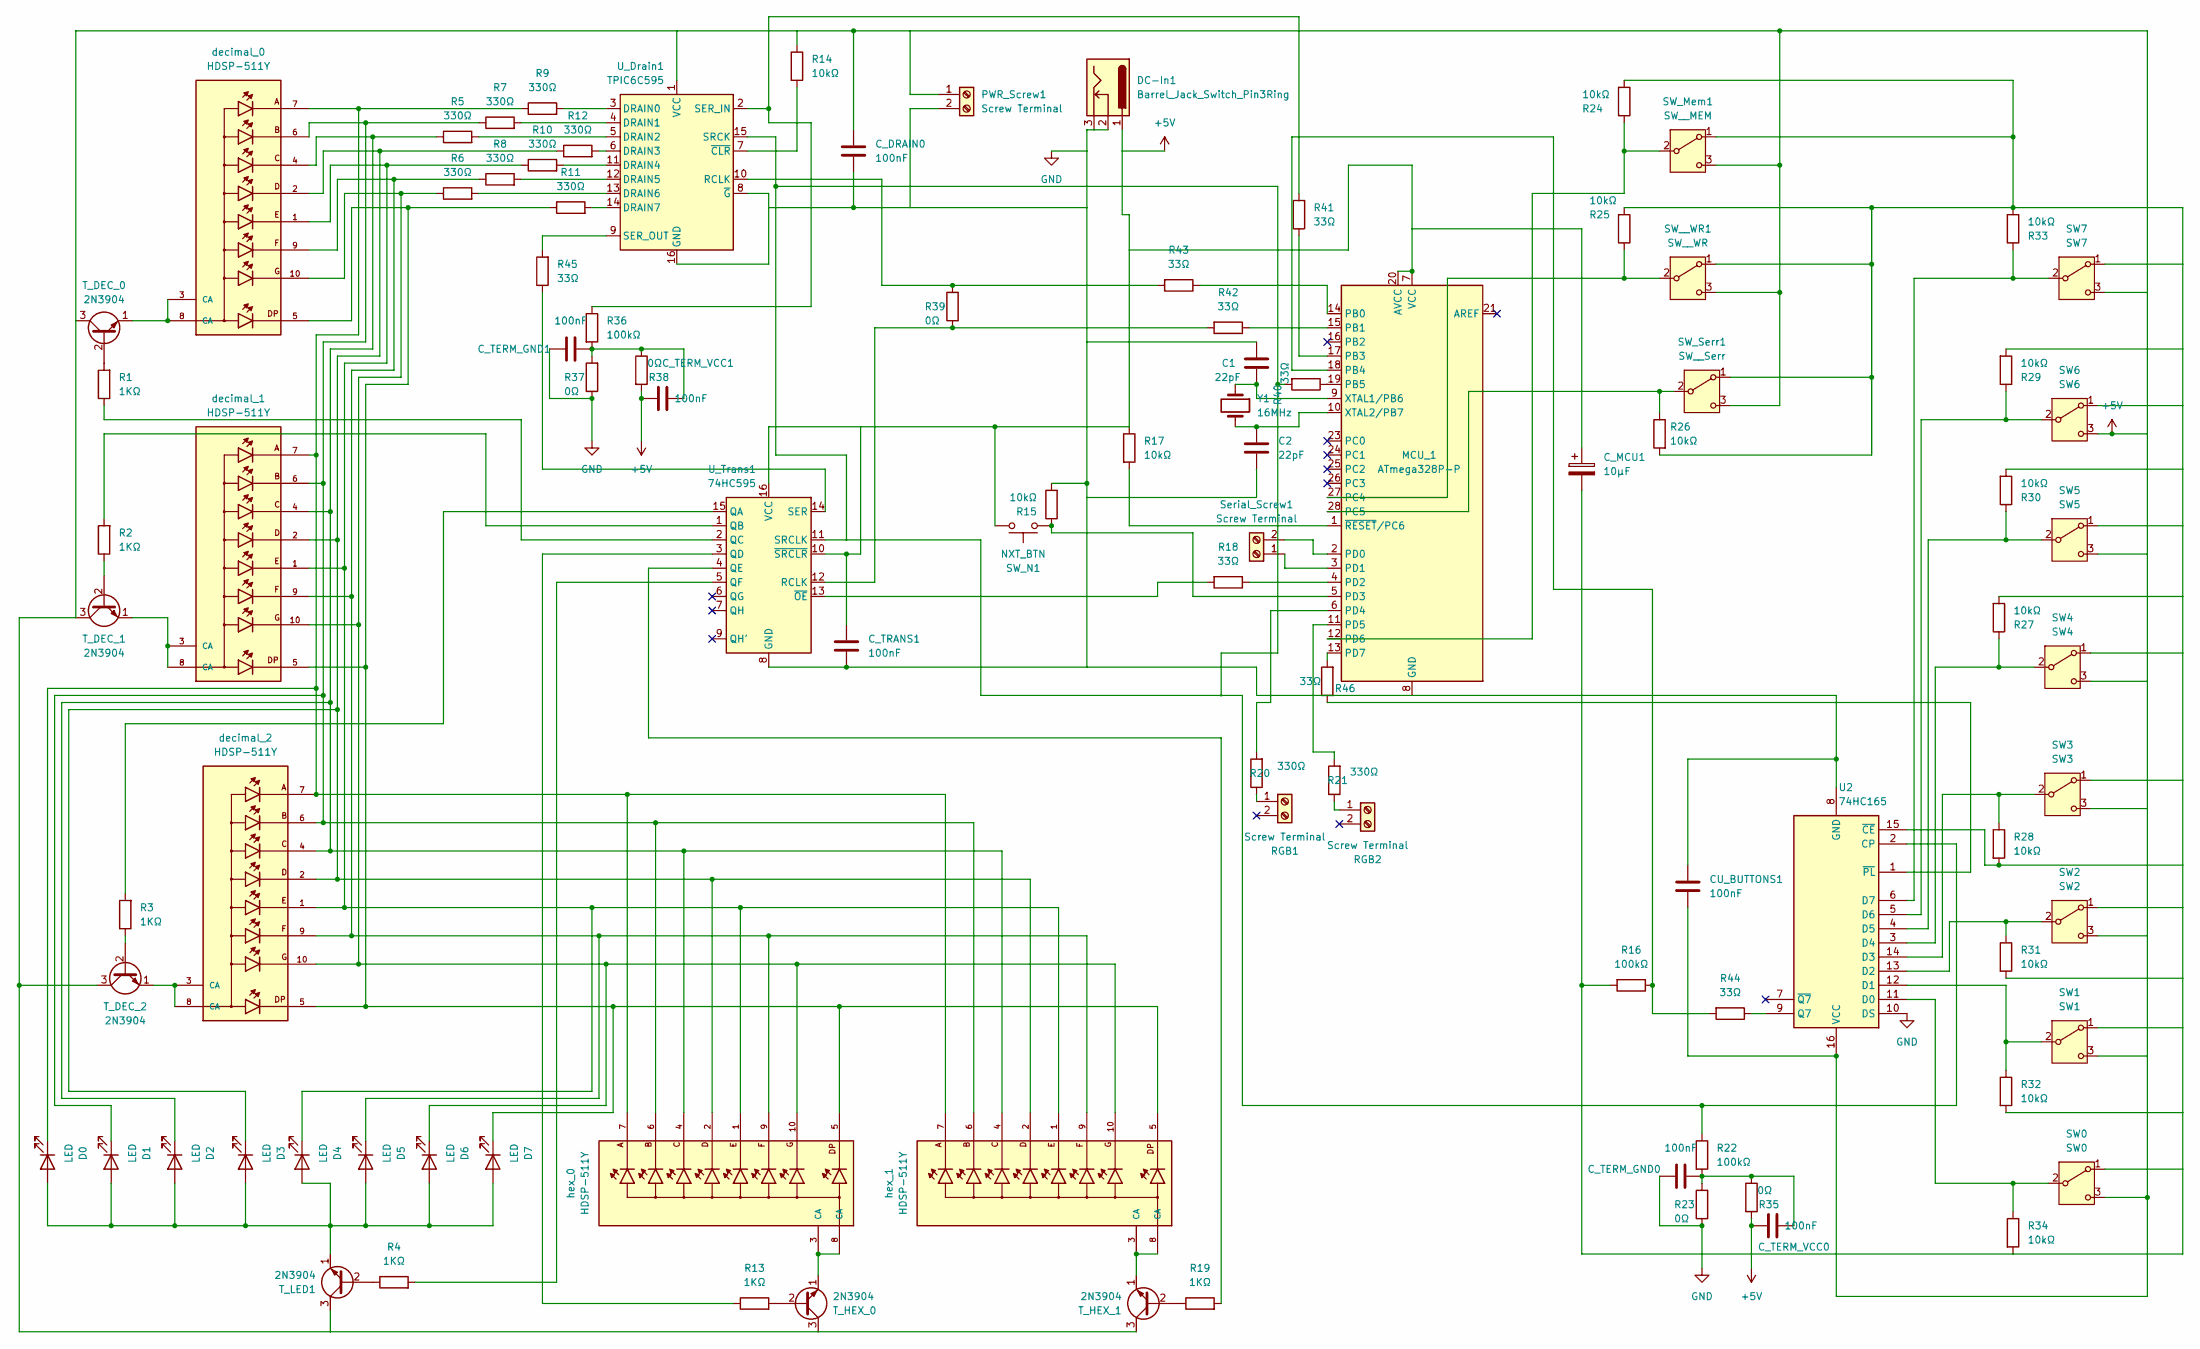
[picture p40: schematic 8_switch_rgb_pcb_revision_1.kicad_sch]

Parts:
C1, C2: 22pF; C_Disc_D3.0mm_W1.6mm_P2.50mm
CU_BUTTONS1: 100nF; C_Disc_D5.0mm_W2.5mm_P5.00mm
C_DRAIN0: 100nF; C_Disc_D5.0mm_W2.5mm_P5.00mm
C_MCU1: 10μF; CP_Radial_D4.0mm_P2.00mm
C_TERM_GND0, C_TERM_GND1: 100nF; C_Disc_D5.0mm_W2.5mm_P5.00mm
C_TERM_VCC0, C_TERM_VCC1: 100nF; C_Disc_D5.0mm_W2.5mm_P5.00mm
C_TRANS1: 100nF; C_Disc_D5.0mm_W2.5mm_P5.00mm
D0, D1, D2, D3, D4, D5, D6, D7: LED; LED_D3.0mm
DC-In1: Barrel_Jack_Switch_Pin3Ring; BarrelJack_CUI_PJ-102AH_Horizontal
MCU_1: ATmega328P-P; DIP-28_W7.62mm_Socket
PWR_Screw1: Screw Terminal; TerminalBlock_Phoenix_MPT-0,5-2-2.54_1x02_P2.54mm_Horizontal
R1, R2, R3, R4, R13, R19: 1KΩ; R_Axial_DIN0207_L6.3mm_D2.5mm_P7.62mm_Horizontal
R5, R6, R7, R8, R9, R10, R11, R12, R20, R21: 330Ω; R_Axial_DIN0207_L6.3mm_D2.5mm_P7.62mm_Horizontal
R14, R15, R17, R24, R25, R26, R27, R28, R29, R30, R31, R32, R33, R34: 10kΩ; R_Axial_DIN0204_L3.6mm_D1.6mm_P5.08mm_Horizontal
R16, R22, R36: 100kΩ; R_Axial_DIN0204_L3.6mm_D1.6mm_P5.08mm_Horizontal
R18, R40, R41, R42, R43, R44, R45, R46: 33Ω; R_Axial_DIN0204_L3.6mm_D1.6mm_P5.08mm_Horizontal
R23, R35, R37, R38: 0Ω; R_Axial_DIN0204_L3.6mm_D1.6mm_P2.54mm_Vertical
R39: 0Ω; R_Axial_DIN0204_L3.6mm_D1.6mm_P5.08mm_Horizontal
RGB1, RGB2: Screw Terminal; TerminalBlock_Phoenix_MPT-0,5-2-2.54_1x02_P2.54mm_Horizontal
SW0: SW0; SW_Toggle_Small
SW1: SW1; SW_Toggle_Small
SW2: SW2; SW_Toggle_Small
SW3: SW3; SW_Toggle_Small
SW4: SW4; SW_Toggle_Small
SW5: SW5; SW_Toggle_Small
SW6: SW6; SW_Toggle_Small
SW7: SW7; SW_Toggle_Small
SW_Mem1: SW__MEM; SW_Toggle_Small
SW_N1: NXT_BTN; SW_PUSH_6mm_H5mm
SW_Serr1: SW__Serr; SW_Toggle_Small
SW__WR1: SW__WR; SW_Toggle_Small
Serial_Screw1: Screw Terminal; TerminalBlock_Phoenix_MPT-0,5-2-2.54_1x02_P2.54mm_Horizontal
T_DEC_0, T_DEC_1, T_DEC_2: 2N3904; TO-92_Inline
T_HEX_0, T_HEX_1: 2N3904; TO-92_Inline
T_LED1: 2N3904; TO-92_Inline
U2: 74HC165; DIP-16_W7.62mm_Socket
U_Drain1: TPIC6C595; DIP-16_W7.62mm_Socket
U_Trans1: 74HC595; DIP-16_W7.62mm_Socket
Y1: 16MHz; Crystal_HC49-4H_Vertical
decimal_0, decimal_1, decimal_2: HDSP-511Y; LED_HDSP-511Y; PARTREV April 12, 2021
hex_0, hex_1: HDSP-511Y; LED_HDSP-511Y; PARTREV April 12, 2021

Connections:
+5V: CU_BUTTONS1.2, C_DRAIN0.1, C_MCU1.1, C_TERM_VCC0.2, C_TERM_VCC1.2, C_TRANS1.1, DC-In1.1, MCU_1.7 (VCC), MCU_1.20 (AVCC), PWR_Screw1.1, R14.1, R17.1, R35.2, R38.2, SW0.3 (C), SW1.3 (C), SW2.3 (C), SW3.3 (C), SW4.3 (C), SW5.3 (C), SW6.3 (C), SW7.3 (C), SW_Mem1.3 (C), SW_N1.2, SW_Serr1.3 (C), SW__WR1.3 (C), T_DEC_0.3 (C), T_DEC_1.3 (C), T_DEC_2.3 (C), T_HEX_0.3 (C), T_HEX_1.3 (C), T_LED1.3 (C), U2.16 (VCC), U_Drain1.1 (VCC), U_Trans1.10 (~SRCLR), U_Trans1.16 (VCC)
GND: C1.1, C2.2, CU_BUTTONS1.1, C_DRAIN0.2, C_MCU1.2, C_TERM_GND0.1, C_TERM_GND1.1, C_TRANS1.2, DC-In1.2, DC-In1.3, MCU_1.8 (GND), MCU_1.22 (GND), PWR_Screw1.2, R15.2, R16.2, R23.1, R24.2, R25.2, R26.2, R27.2, R28.2, R29.2, R30.2, R31.2, R32.2, R33.2, R34.2, R37.1, SW0.1 (A), SW1.1 (A), SW2.1 (A), SW3.1 (A), SW4.1 (A), SW5.1 (A), SW6.1 (A), SW7.1 (A), SW_Mem1.1 (A), SW_Serr1.1 (A), SW__WR1.1 (A), U2.8 (GND), U2.10 (DS), U2.15 (~CE), U_Drain1.8 (~G), U_Drain1.16 (GND), U_Trans1.8 (GND)
unnamed: C_TERM_GND0.2, C_TERM_VCC0.1, R22.2, R23.2, R35.1
unnamed: C_TERM_GND1.2, C_TERM_VCC1.1, R36.2, R37.2, R38.1
unnamed: D0.2 (A), D1.2 (A), D2.2 (A), D3.2 (A), D4.2 (A), D5.2 (A), D6.2 (A), D7.2 (A), T_LED1.1 (E)
unnamed: D0.1 (K), R9.1, decimal_0.7, decimal_1.7, decimal_2.7, hex_0.7, hex_1.7
unnamed: D1.1 (K), R7.1, decimal_0.6, decimal_1.6, decimal_2.6, hex_0.6, hex_1.6
unnamed: D2.1 (K), R5.1, decimal_0.4, decimal_1.4, decimal_2.4, hex_0.4, hex_1.4
unnamed: D3.1 (K), R12.1, decimal_0.2, decimal_1.2, decimal_2.2, hex_0.2, hex_1.2
unnamed: D4.1 (K), R10.1, decimal_0.1, decimal_1.1, decimal_2.1, hex_0.1, hex_1.1
unnamed: D5.1 (K), R8.1, decimal_0.9, decimal_1.9, decimal_2.9, hex_0.9, hex_1.9
unnamed: D6.1 (K), R6.1, decimal_0.10, decimal_1.10, decimal_2.10, hex_0.10, hex_1.10
unnamed: D7.1 (K), R11.1, decimal_0.5, decimal_1.5, decimal_2.5, hex_0.5, hex_1.5
unnamed: MCU_1.14 (PB0), R43.1
unnamed: MCU_1.15 (PB1), R42.1
unnamed: MCU_1.17 (PB3), R41.1
unnamed: MCU_1.18 (PB4), R16.1, R44.2
unnamed: MCU_1.19 (PB5), R40.1
unnamed: MCU_1.27 (PC4), R25.1, SW__WR1.2 (B)
unnamed: MCU_1.28 (PC5), R26.1, SW_Serr1.2 (B)
unnamed: MCU_1.2 (PD0), Serial_Screw1.2
unnamed: MCU_1.3 (PD1), Serial_Screw1.1
unnamed: MCU_1.4 (PD2), R18.1
unnamed: MCU_1.5 (PD3), R15.1, SW_N1.1
unnamed: MCU_1.6 (PD4), R20.2
unnamed: MCU_1.11 (PD5), R21.2
unnamed: MCU_1.12 (PD6), R24.1, SW_Mem1.2 (B)
unnamed: MCU_1.13 (PD7), R46.2
unnamed: C1.2, MCU_1.9 (XTAL1/PB6), Y1.1
unnamed: C2.1, MCU_1.10 (XTAL2/PB7), Y1.2
unnamed: MCU_1.1 (~RESET/PC6), R17.2
unnamed: R20.1, RGB1.1
unnamed: R21.1, RGB2.1
unnamed: R34.1, SW0.2 (B), U2.11 (D0)
unnamed: R32.1, SW1.2 (B), U2.12 (D1)
unnamed: R31.1, SW2.2 (B), U2.13 (D2)
unnamed: R28.1, SW3.2 (B), U2.14 (D3)
unnamed: R27.1, SW4.2 (B), U2.3 (D4)
unnamed: R30.1, SW5.2 (B), U2.4 (D5)
unnamed: R29.1, SW6.2 (B), U2.5 (D6)
unnamed: R33.1, SW7.2 (B), U2.6 (D7)
unnamed: R1.2, T_DEC_0.2 (B)
unnamed: T_DEC_0.1 (E), decimal_0.3 (CA), decimal_0.8 (CA)
unnamed: R2.1, T_DEC_1.2 (B)
unnamed: T_DEC_1.1 (E), decimal_1.3 (CA), decimal_1.8 (CA)
unnamed: R3.1, T_DEC_2.2 (B)
unnamed: T_DEC_2.1 (E), decimal_2.3 (CA), decimal_2.8 (CA)
unnamed: R13.2, T_HEX_0.2 (B)
unnamed: T_HEX_0.1 (E), hex_0.3 (CA), hex_0.8 (CA)
unnamed: R19.1, T_HEX_1.2 (B)
unnamed: T_HEX_1.1 (E), hex_1.3 (CA), hex_1.8 (CA)
unnamed: R4.1, T_LED1.2 (B)
unnamed: R22.1, R40.2, U2.2 (CP), U_Drain1.15 (SRCK), U_Trans1.11 (SRCLK)
unnamed: R44.1, U2.9 (Q7)
unnamed: R46.1, U2.1 (~PL)
unnamed: R9.2, U_Drain1.3 (DRAIN0)
unnamed: R7.2, U_Drain1.4 (DRAIN1)
unnamed: R5.2, U_Drain1.5 (DRAIN2)
unnamed: R12.2, U_Drain1.6 (DRAIN3)
unnamed: R10.2, U_Drain1.11 (DRAIN4)
unnamed: R8.2, U_Drain1.12 (DRAIN5)
unnamed: R6.2, U_Drain1.13 (DRAIN6)
unnamed: R11.2, U_Drain1.14 (DRAIN7)
unnamed: R39.2, R43.2, U_Drain1.10 (RCLK)
unnamed: R36.1, R41.2, U_Drain1.2 (SER_IN)
unnamed: R45.2, U_Drain1.9 (SER_OUT)
unnamed: R14.2, U_Drain1.7 (~CLR)
unnamed: R3.2, U_Trans1.15 (QA)
unnamed: R2.2, U_Trans1.1 (QB)
unnamed: R1.1, U_Trans1.2 (QC)
unnamed: R13.1, U_Trans1.3 (QD)
unnamed: R19.2, U_Trans1.4 (QE)
unnamed: R4.2, U_Trans1.5 (QF)
unnamed: R39.1, R42.2, U_Trans1.12 (RCLK)
unnamed: R45.1, U_Trans1.14 (SER)
unnamed: R18.2, U_Trans1.13 (~OE)

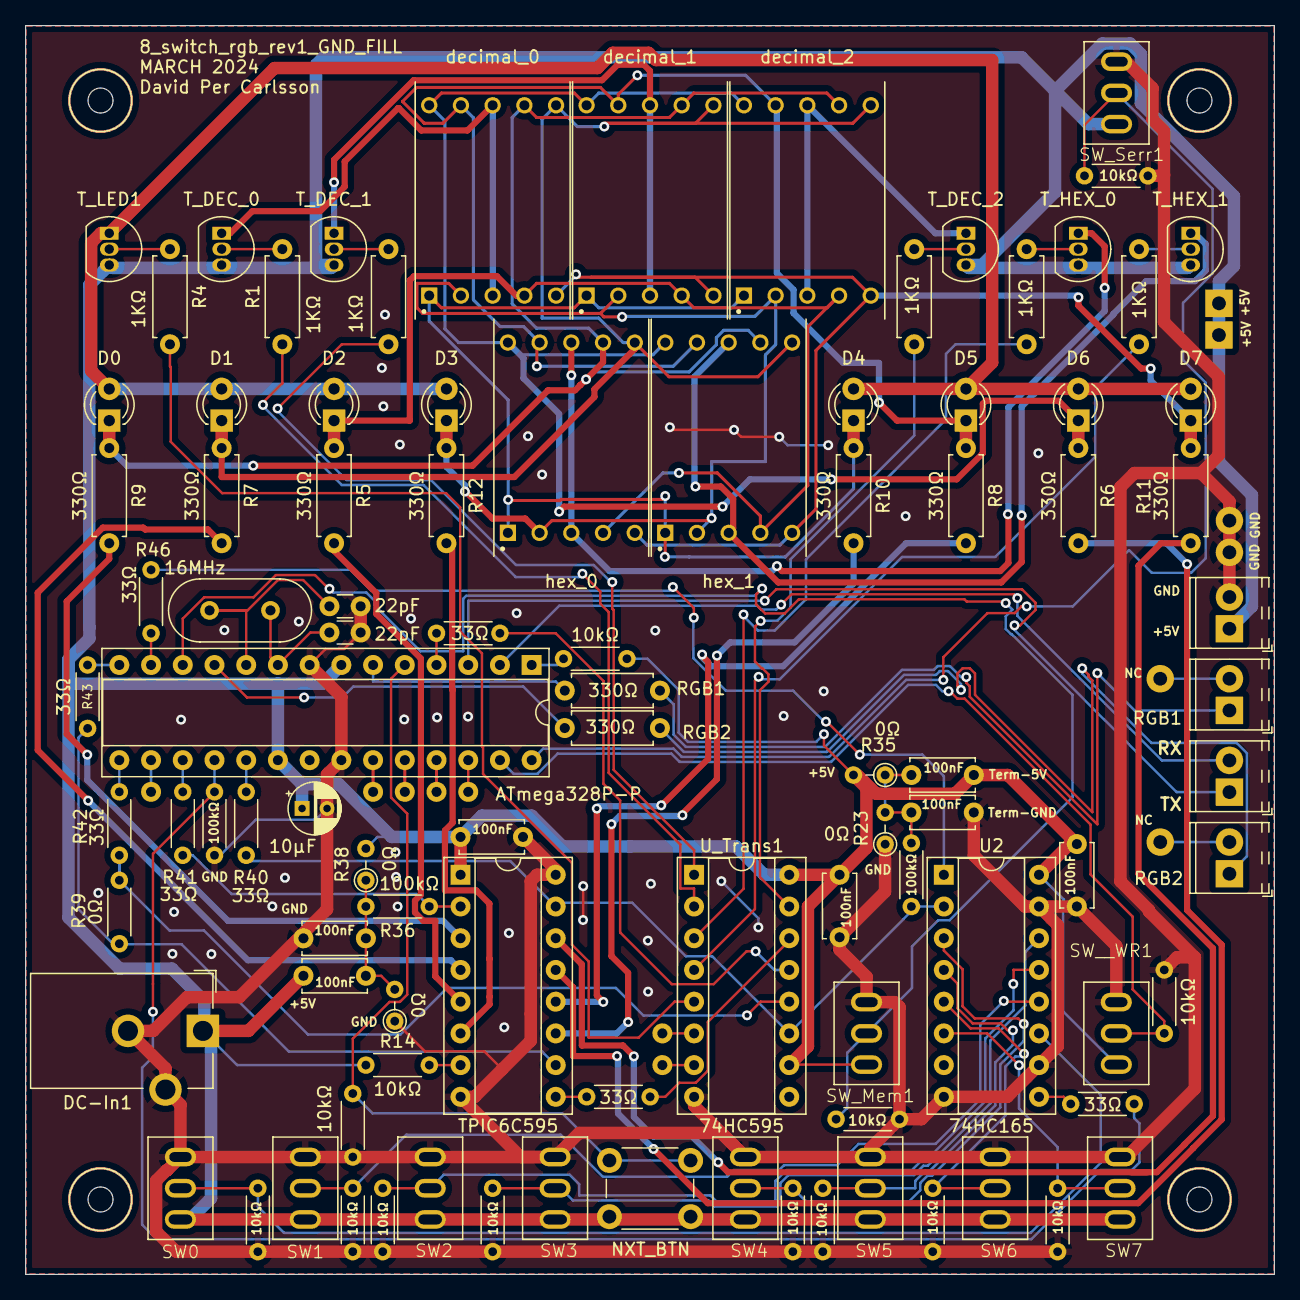
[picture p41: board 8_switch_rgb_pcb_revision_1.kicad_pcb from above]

Board: 2 copper layers, 100.0 x 100.0 mm, 97 parts (0 on the bottom side), 76 nets.

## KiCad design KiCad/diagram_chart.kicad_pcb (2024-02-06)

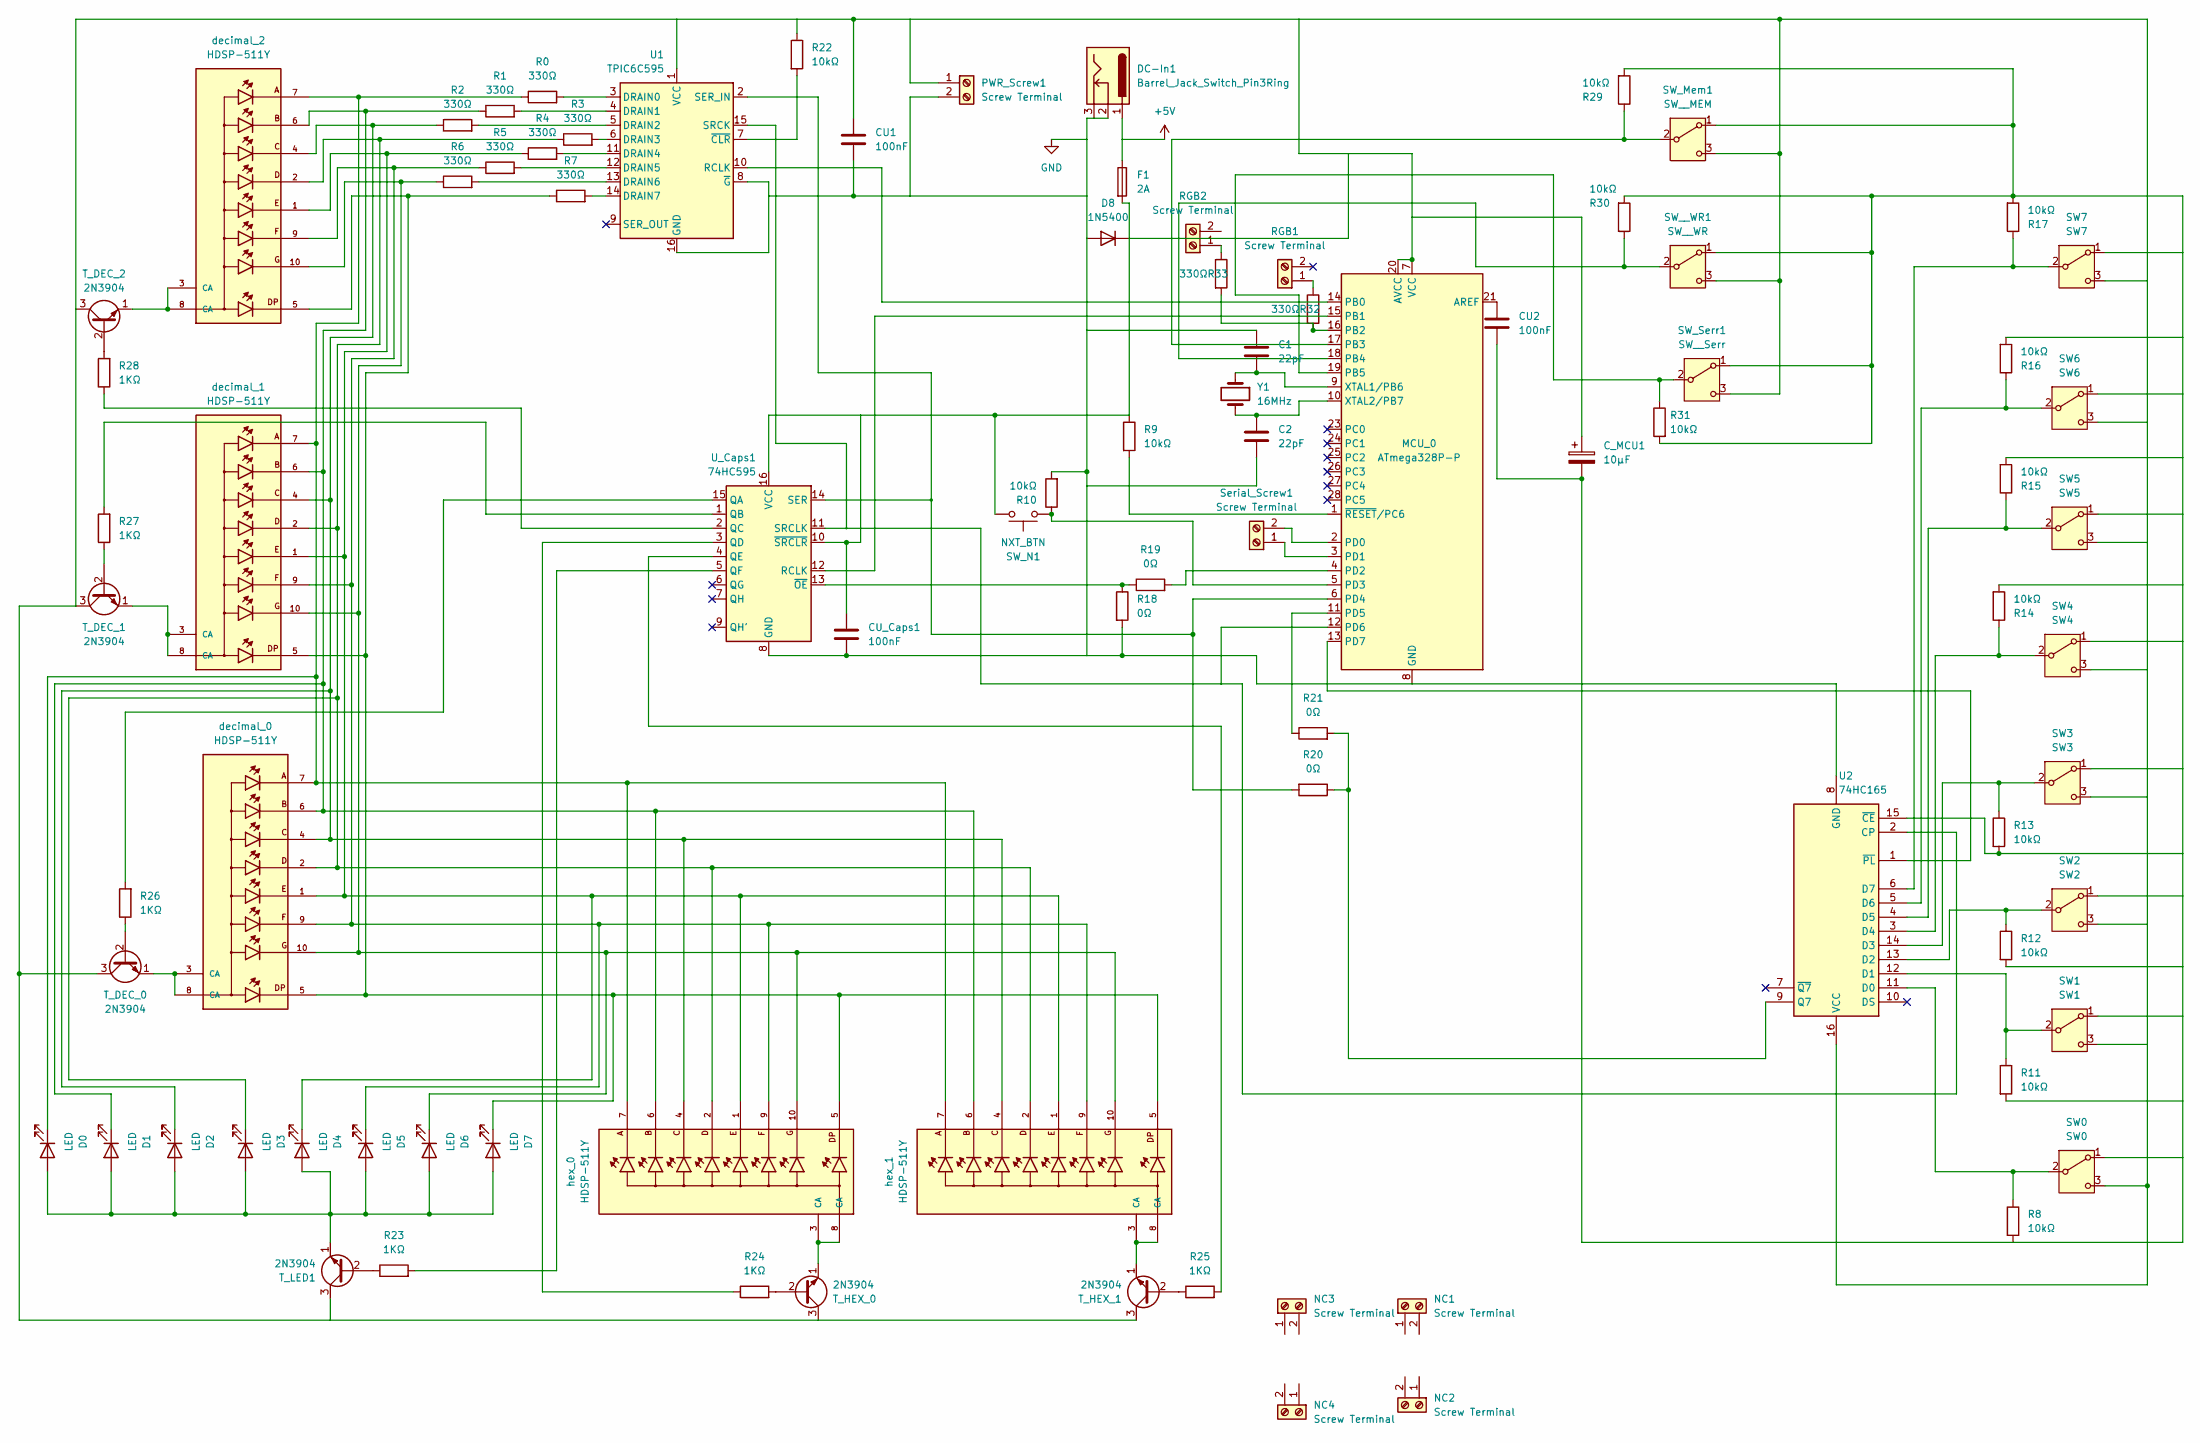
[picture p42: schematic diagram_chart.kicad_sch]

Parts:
C1, C2: 22pF; C_Disc_D3.0mm_W1.6mm_P2.50mm
CU1, CU2: 100nF; C_Disc_D3.0mm_W1.6mm_P2.50mm
CU_Caps1: 100nF; C_Disc_D3.0mm_W1.6mm_P2.50mm
C_MCU1: 10μF; CP_Radial_D4.0mm_P2.00mm
D0, D1, D2, D3, D4, D5, D6, D7: LED; LED_D3.0mm
D8: 1N5400; D_DO-201AD_P15.24mm_Horizontal
DC-In1: Barrel_Jack_Switch_Pin3Ring; BarrelJack_CUI_PJ-102AH_Horizontal
F1: 2A; Fuseholder_Clip-5x20mm_Eaton_1A5601-01_Inline_P20.80x6.76mm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
MCU_0: ATmega328P-P; DIP-28_W7.62mm_Socket
NC1, NC2, NC3, NC4: Screw Terminal; TerminalBlock_Phoenix_MPT-0,5-2-2.54_1x02_P2.54mm_Horizontal
PWR_Screw1: Screw Terminal; TerminalBlock_Phoenix_MPT-0,5-2-2.54_1x02_P2.54mm_Horizontal
R0, R1, R2, R3, R4, R5, R6, R7, R32, R33: 330Ω; R_Axial_DIN0207_L6.3mm_D2.5mm_P7.62mm_Horizontal
R8, R9, R10, R11, R12, R13, R14, R15, R16, R17, R22, R29, R30, R31: 10kΩ; R_Axial_DIN0204_L3.6mm_D1.6mm_P5.08mm_Horizontal
R18, R19, R20, R21: 0Ω; R_Axial_DIN0204_L3.6mm_D1.6mm_P2.54mm_Vertical
R23, R24, R25, R26, R27, R28: 1KΩ; R_Axial_DIN0207_L6.3mm_D2.5mm_P7.62mm_Horizontal
RGB1, RGB2: Screw Terminal; TerminalBlock_Phoenix_MPT-0,5-2-2.54_1x02_P2.54mm_Horizontal
SW0: SW0; SW_Toggle_Blue_SMALL
SW1: SW1; SW_Toggle_Blue_SMALL
SW2: SW2; SW_Toggle_Blue_SMALL
SW3: SW3; SW_Toggle_Blue_SMALL
SW4: SW4; SW_Toggle_Blue_SMALL
SW5: SW5; SW_Toggle_Blue_SMALL
SW6: SW6; SW_Toggle_Blue_SMALL
SW7: SW7; SW_Toggle_Blue_SMALL
SW_Mem1: SW__MEM; SW_Toggle_Blue_SMALL
SW_N1: NXT_BTN; SW_PUSH_6mm_H5mm
SW_Serr1: SW__Serr; SW_Toggle_Blue_SMALL
SW__WR1: SW__WR; SW_Toggle_Blue_SMALL
Serial_Screw1: Screw Terminal; TerminalBlock_Phoenix_MPT-0,5-2-2.54_1x02_P2.54mm_Horizontal
T_DEC_0, T_DEC_1, T_DEC_2: 2N3904; TO-92_Inline
T_HEX_0, T_HEX_1: 2N3904; TO-92_Inline
T_LED1: 2N3904; TO-92_Inline
U1: TPIC6C595; DIP-16_W7.62mm_Socket
U2: 74HC165; DIP-16_W7.62mm_Socket
U_Caps1: 74HC595; DIP-16_W7.62mm_Socket
Y1: 16MHz; Crystal_HC49-4H_Vertical
decimal_0, decimal_1, decimal_2: HDSP-511Y; LED_HDSP-511Y; PARTREV April 12, 2021
hex_0, hex_1: HDSP-511Y; LED_HDSP-511Y; PARTREV April 12, 2021

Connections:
+5V: DC-In1.1, F1.1
GND: C1.1, C2.2, CU1.2, CU2.2, CU_Caps1.2, C_MCU1.2, D8.2 (A), DC-In1.2, DC-In1.3, MCU_0.8 (GND), MCU_0.22 (GND), PWR_Screw1.2, R8.2, R10.2, R11.2, R12.2, R13.2, R14.2, R15.2, R16.2, R17.2, R18.2, R29.2, R30.2, R31.2, SW0.1 (A), SW1.1 (A), SW2.1 (A), SW3.1 (A), SW4.1 (A), SW5.1 (A), SW6.1 (A), SW7.1 (A), SW_Mem1.1 (A), SW_Serr1.1 (A), SW__WR1.1 (A), U1.8 (~G), U1.16 (GND), U2.8 (GND), U2.15 (~CE), U_Caps1.8 (GND); also elsewhere on the board
unnamed: D0.2 (A), D1.2 (A), D2.2 (A), D3.2 (A), D4.2 (A), D5.2 (A), D6.2 (A), D7.2 (A), T_LED1.1 (E)
unnamed: D0.1 (K), R0.1, decimal_0.7, decimal_1.7, decimal_2.7, hex_0.7, hex_1.7
unnamed: D1.1 (K), R1.1, decimal_0.6, decimal_1.6, decimal_2.6, hex_0.6, hex_1.6
unnamed: D2.1 (K), R2.1, decimal_0.4, decimal_1.4, decimal_2.4, hex_0.4, hex_1.4
unnamed: D3.1 (K), R3.1, decimal_0.2, decimal_1.2, decimal_2.2, hex_0.2, hex_1.2
unnamed: D4.1 (K), R4.1, decimal_0.1, decimal_1.1, decimal_2.1, hex_0.1, hex_1.1
unnamed: D5.1 (K), R5.1, decimal_0.9, decimal_1.9, decimal_2.9, hex_0.9, hex_1.9
unnamed: D6.1 (K), R6.1, decimal_0.10, decimal_1.10, decimal_2.10, hex_0.10, hex_1.10
unnamed: D7.1 (K), R7.1, decimal_0.5, decimal_1.5, decimal_2.5, hex_0.5, hex_1.5
unnamed 11: CU1.1, CU_Caps1.1, C_MCU1.1, D8.1 (K), F1.2, MCU_0.7 (VCC), MCU_0.20 (AVCC), PWR_Screw1.1, R9.1, R22.1, SW0.3 (C), SW1.3 (C), SW2.3 (C), SW3.3 (C), SW4.3 (C), SW5.3 (C), SW6.3 (C), SW7.3 (C), SW_Mem1.3 (C), SW_N1.2, SW_Serr1.3 (C), SW__WR1.3 (C), T_DEC_0.3 (C), T_DEC_1.3 (C), T_DEC_2.3 (C), T_HEX_0.3 (C), T_HEX_1.3 (C), T_LED1.3 (C), U1.1 (VCC), U2.16 (VCC), U_Caps1.10 (~SRCLR), U_Caps1.16 (VCC); also elsewhere on the board
unnamed: CU2.1, MCU_0.21 (AREF)
unnamed: MCU_0.14 (PB0), U1.10 (RCLK)
unnamed: MCU_0.15 (PB1), U_Caps1.12 (RCLK)
unnamed: MCU_0.16 (PB2), R32.2, R33.2
unnamed: MCU_0.17 (PB3), R29.1, SW_Mem1.2 (B)
unnamed: MCU_0.18 (PB4), R30.1, SW__WR1.2 (B)
unnamed: MCU_0.19 (PB5), R31.1, SW_Serr1.2 (B)
unnamed 19: MCU_0.2 (PD0), Serial_Screw1.2; also elsewhere on the board
unnamed 20: MCU_0.3 (PD1), Serial_Screw1.1; also elsewhere on the board
unnamed: MCU_0.4 (PD2), R19.2
unnamed: MCU_0.5 (PD3), R10.1, SW_N1.1
unnamed: MCU_0.6 (PD4), R20.2, U1.2 (SER_IN), U_Caps1.14 (SER)
unnamed: MCU_0.11 (PD5), R21.1
unnamed: MCU_0.12 (PD6), U1.15 (SRCK), U2.2 (CP), U_Caps1.11 (SRCLK)
unnamed: MCU_0.13 (PD7), U2.1 (~PL)
unnamed: C1.2, MCU_0.9 (XTAL1/PB6), Y1.1
unnamed: C2.1, MCU_0.10 (XTAL2/PB7), Y1.2
unnamed: MCU_0.1 (~RESET/PC6), R9.2
unnamed: R32.1, RGB1.1
unnamed: R33.1, RGB2.1
unnamed: R8.1, SW0.2 (B), U2.11 (D0)
unnamed: R11.1, SW1.2 (B), U2.12 (D1)
unnamed: R12.1, SW2.2 (B), U2.13 (D2)
unnamed: R13.1, SW3.2 (B), U2.14 (D3)
unnamed: R14.1, SW4.2 (B), U2.3 (D4)
unnamed: R15.1, SW5.2 (B), U2.4 (D5)
unnamed: R16.1, SW6.2 (B), U2.5 (D6)
unnamed: R17.1, SW7.2 (B), U2.6 (D7)
unnamed: R26.1, T_DEC_0.2 (B)
unnamed: T_DEC_0.1 (E), decimal_0.3 (CA), decimal_0.8 (CA)
unnamed: R27.1, T_DEC_1.2 (B)
unnamed: T_DEC_1.1 (E), decimal_1.3 (CA), decimal_1.8 (CA)
unnamed: R28.2, T_DEC_2.2 (B)
unnamed: T_DEC_2.1 (E), decimal_2.3 (CA), decimal_2.8 (CA)
unnamed: R24.2, T_HEX_0.2 (B)
unnamed: T_HEX_0.1 (E), hex_0.3 (CA), hex_0.8 (CA)
unnamed: R25.1, T_HEX_1.2 (B)
unnamed: T_HEX_1.1 (E), hex_1.3 (CA), hex_1.8 (CA)
unnamed: R23.1, T_LED1.2 (B)
unnamed: R0.2, U1.3 (DRAIN0)
unnamed: R1.2, U1.4 (DRAIN1)
unnamed: R2.2, U1.5 (DRAIN2)
unnamed: R3.2, U1.6 (DRAIN3)
unnamed: R4.2, U1.11 (DRAIN4)
unnamed: R5.2, U1.12 (DRAIN5)
unnamed: R6.2, U1.13 (DRAIN6)
unnamed: R7.2, U1.14 (DRAIN7)
unnamed: R22.2, U1.7 (~CLR)
unnamed: R20.1, R21.2, U2.9 (Q7)
unnamed: R26.2, U_Caps1.15 (QA)
unnamed: R27.2, U_Caps1.1 (QB)
unnamed: R28.1, U_Caps1.2 (QC)
unnamed: R24.1, U_Caps1.3 (QD)
unnamed: R25.2, U_Caps1.4 (QE)
unnamed: R23.2, U_Caps1.5 (QF)
unnamed: R18.1, R19.1, U_Caps1.13 (~OE)

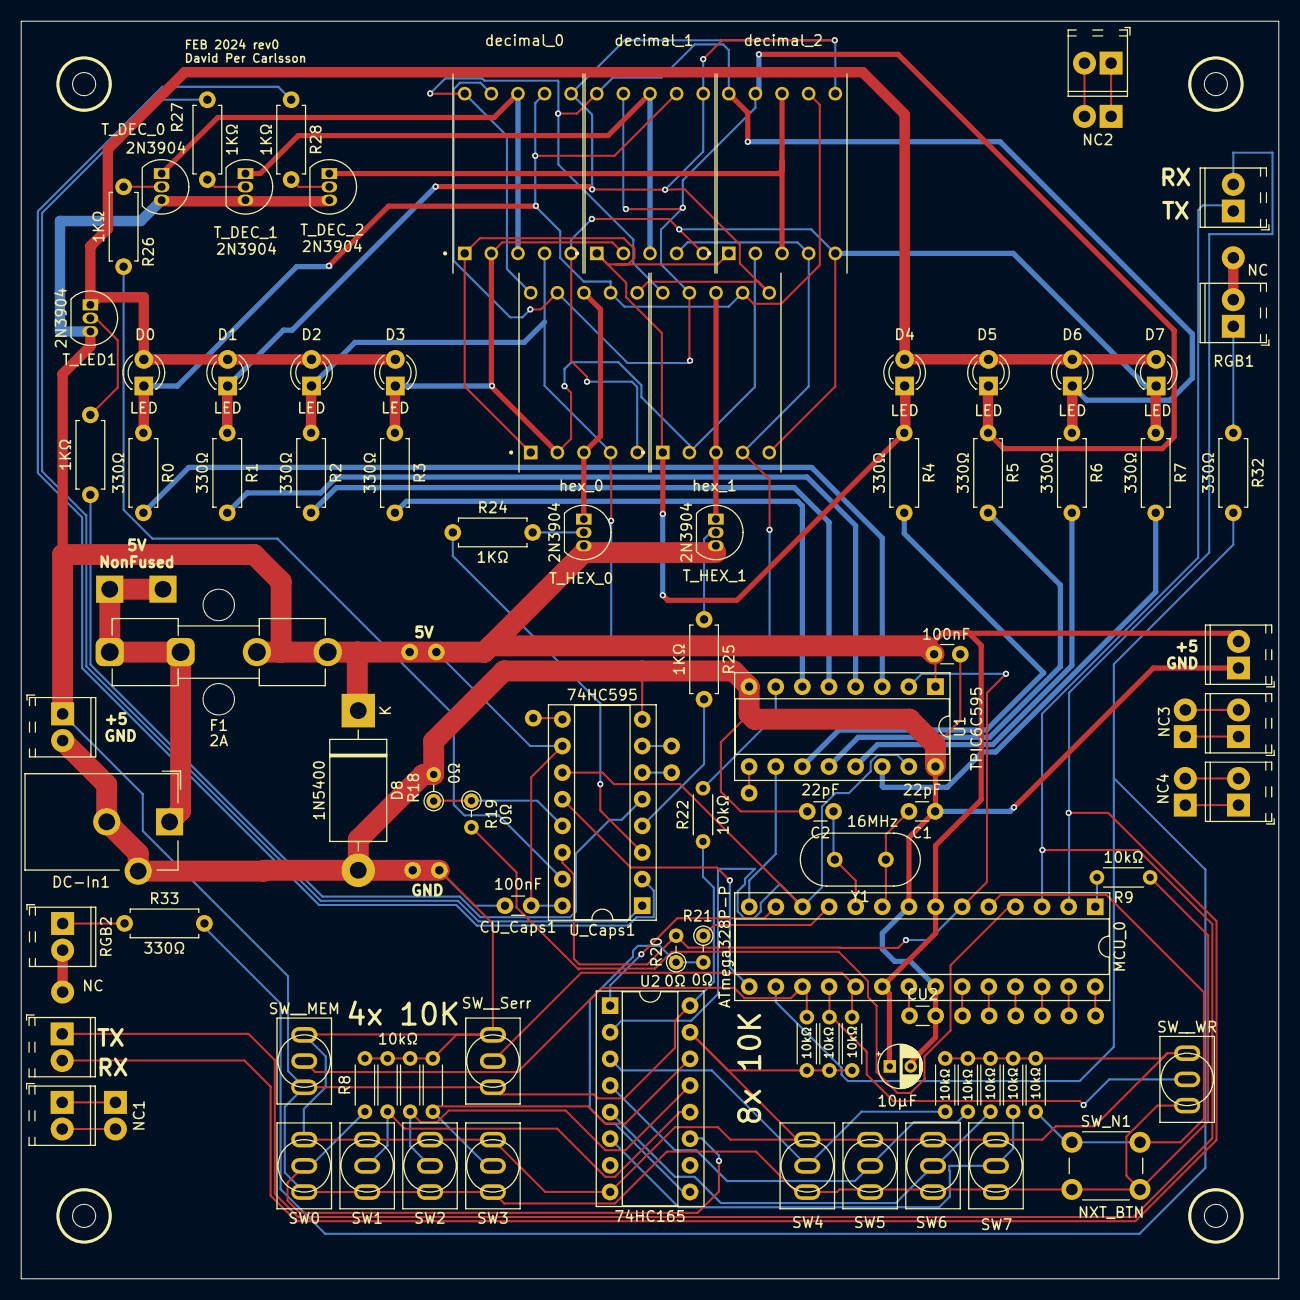
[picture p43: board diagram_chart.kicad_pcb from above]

Board: 2 copper layers, 120.0 x 120.0 mm, 89 parts (0 on the bottom side), 68 nets.

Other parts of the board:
PWR_Screw2: Screw Terminal; TerminalBlock_Phoenix_MPT-0,5-2-2.54_1x02_P2.54mm_Horizontal
Serial_Screw1#2: Screw Terminal; TerminalBlock_Phoenix_MPT-0,5-2-2.54_1x02_P2.54mm_Horizontal

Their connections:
GND: PWR_Screw2.1; also elsewhere on the board
unnamed 11: PWR_Screw2.2; also elsewhere on the board
unnamed 19: Serial_Screw1#2.2; also elsewhere on the board
unnamed 20: Serial_Screw1#2.1; also elsewhere on the board

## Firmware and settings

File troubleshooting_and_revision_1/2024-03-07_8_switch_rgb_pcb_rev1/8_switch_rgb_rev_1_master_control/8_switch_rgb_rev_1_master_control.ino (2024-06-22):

/*
 * Future refactor may want to take this into account:
 * https://github.com/FastLED/FastLED/wiki/Multiple-Controller-Examples#managing-your-own-output
 */

#include <SPI.h>
#include <EEPROM.h>
#include <FastLED.h>
#define NUM_LEDS 5
#define NUM_LEDS_RGB2 4

#define BUTTON 3 //5
#define SW_MEM 6 //12
/*
  //Correct order:

  #define SW_WR A4 //27
  #define SW_SERR A5 //28
*/
//More ergonomic order (mostly relevant when using it as a calculator):
#define SW_SERR A4 //27
#define SW_WR A5 //28
/**/
#define OUTPUT_ENABLE 2 //4
#define RCK_INPUT 7 //13
#define RCK_OUTPUT 8 //14
#define RCK_TRANS 9 //15
#define RGB1_PIN 4 //6
#define RGB2_PIN 5 //11

const bool isDebug = false;
// If LED-strip is letting Current and Signal pass Right to Left instead of Left to Right:
const bool isLedsReversed = true;

//if SW_WR is HIGH when SW_SERR has been HIGH, Non-Volatile: EEPROM 5.
volatile bool isOff = false;
const byte eepromOff = 5; //EEPROM address of above boolean.

volatile bool isCounter = false;
volatile bool isBlackout = false;

volatile unsigned long lastCount = 0;
volatile unsigned long updateInterval = 100;

// Define the array of LEDs for the primary output
CRGB leds[NUM_LEDS];
// Define the array of LEDs for the secondary output
//This will only be written to on "blackout"
CRGB leds_rgb2[NUM_LEDS_RGB2];

volatile byte color = 0; //r,g,b,NO color
const byte colorAddresses[] = {1, 2, 3, 4}; //Addresses for EEPROM/R,G,B; NONE
volatile byte channelValues[] = {0b10000000, 0b10000000, 0b10000000, 0b00000000}; //R,G,B; NONE

const byte customChars[] = {
  B11111100, // 0
  B01100000, // 1
  B11011010, // 2
  B11110010, // 3
  B01100110, // 4
  B10110110, // 5
  B10111110, // 6
  B11100000, // 7
  B11111110, // 8
  B11100110, // 9
  B11101110, // a
  B00111110, // b
  B10011100, // c
  B01111010, // d
  B10011110, // e
  B10001110  // f
};
/*
  //Logic order output addresses:
  const byte outputs[6]  =
  {
  0b10000000,
  0b01000000,
  0b00100000,
  0b00010000,
  0b00001000,
  0b00000100,
  };
*/
//Actual order output addresses:
const byte outputs[6]  =
{
  0b00100000,
  0b01000000,
  0b10000000,
  0b00010000,
  0b00001000,
  0b00000100,
};
/**/

volatile byte outputValues[6] = {
  0b11000000,
  0b01000000,
  0b00100000,
  0b00010000,
  0b00001000,
  0b00000101,
};

volatile char outputChars[6];
volatile byte counter = 0x00;

volatile byte switchValues = 0b10000000;

volatile unsigned long button_time = 0;
volatile unsigned long last_button_time = 0;

volatile unsigned long buttonTime = 0;
volatile unsigned long lastButtonActive = 0;
volatile bool buttonToggled = false;

void buttonHigh() {
  if (buttonTime == 0) {
    buttonTime = millis();
  }
  else if (buttonTime - lastButtonActive > 100 && buttonToggled == false)
  {
    if (isCounter) {
      switch (updateInterval)
      {

        case 5000:
          updateInterval = 2000;
          break;
        case 2000:
          updateInterval = 1000;
          break;
        case 1000:
          updateInterval = 500;
          break;
        case 500:
          updateInterval = 250;
          break;
        case 250:
          updateInterval = 100;
          break;
        case 100:
          updateInterval = 50;
          break;
        case 50:
          updateInterval = 10;
          break;
        case 10:
          updateInterval = 5000;
          break;
        default:
          updateInterval = 100;
          break;
      }
    }
    else {
      if (color == 3) {
        color = 0;
      } else {
        color += 1;
      }
      setLedColors();
    }
    buttonToggled = true;
  }
}

long selectedColor() {
  switch (color)
  {
    case 0:
      return CRGB::Red;
    case 1:
      return CRGB::Green;
    case 2:
      return CRGB::Blue;
    case 3:
      return CRGB::Black;
  }
}

/**
   Sets and shows the selected color according to different modes.
*/
void setLedColors() {
  if (isOff) {
    for (int i = 0; i < NUM_LEDS; i++) {
      leds[i] = CRGB::Black;
    }
  } else if (isBlackout) {
    for (int i = 0; i < NUM_LEDS; i++) {
      leds[i] = CRGB(channelValues[0], channelValues[1], channelValues[2]);
    }
  }
  else {
    if (isLedsReversed) {
      leds[4] = selectedColor();
      leds[3] = CRGB(channelValues[0], 0, 0);
      leds[2] = CRGB(0, channelValues[1], 0);
      leds[1] = CRGB(0, 0, channelValues[2]);

      leds[0] = CRGB(channelValues[0], channelValues[1], channelValues[2]);
    }
    else {
      leds[0] = selectedColor();
      leds[1] = CRGB(channelValues[0], 0, 0);
      leds[2] = CRGB(0, channelValues[1], 0);
      leds[3] = CRGB(0, 0, channelValues[2]);

      leds[4] = CRGB(channelValues[0], channelValues[1], channelValues[2]);
    }
  }
  leds_rgb2 [0] = leds[0];
  leds_rgb2 [1] = leds[1];
  leds_rgb2 [2] = leds[2];
  leds_rgb2 [3] = leds[3];
  
  FastLED.show();
}

void printByte(byte val) {
  for (int i = 7; i >= 0; i--)
  {
    bool b = bitRead(val, i);
    Serial.print(b);
  }
}

byte charToByte(char ch) {
  // Validate input character
  if ((ch >= '0' && ch <= '9') || (ch >= 'A' && ch <= 'F')) {
    // Handle decimal or hexadecimal character
    int value;
    if (ch >= '0' && ch <= '9') {
      value = ch - '0';
    } else {
      value = ch - 'A' + 10; // Convert hex char to numerical value (A-F: 10-15)
    }
    return value;
    //return value << 4; // Shift left by 4 bits (No idea why I would want to?)
  } else {
    // Return 0 for invalid characters
    return 0;
  }
}
/*
  Given a value this will change the different arrays so their values are representative for later use.
*/
void setOutputValues(byte value) {
  // Convert to decimal string manually
  String strValue = String(value);
  // Handle single-digit values
  if (strValue.length() == 1)
    strValue = "00" + strValue; // Prepend leading zeros
  else if (strValue.length() == 2)
    strValue = "0" + strValue; // Prepend leading zeros
  strValue.toCharArray(outputChars, sizeof(outputChars)); // Copy to char array
  for (int i = 0; i < 3; i++) {
    outputValues[i] = customChars[charToByte(outputChars[i])];
  }

  // Convert to hexadecimal string manually
  byte nibble;
  for (int i = 0; i < 2; i++) {
    nibble = (value >> (4 * i)) & 0x0F;
    outputChars[4 - i] = (nibble < 10) ? '0' + nibble : 'A' + nibble - 10;
    outputValues[4 - i] = customChars[nibble];
  }
  outputChars[5] = char(value);
  outputValues[5] = value;
}

/*
  Sets the decimal displays to display "OFF", all other displays are black/empty.
*/
void setOutputValuesOff() {
  // Convert to decimal string manually
  String strValue = "0FF";
  strValue.toCharArray(outputChars, sizeof(outputChars)); // Copy to char array
  for (int i = 0; i < 3; i++) {
    outputValues[i] = customChars[charToByte(outputChars[i])];
  }

  for (int i = 0; i < 2; i++) {
    outputChars[4 - i] = 0;
    outputValues[4 - i] = 0x00;
  }
  outputChars[5] = 0;
  outputValues[5] = 0x00;
}

/**
  Reads inputs from 74hc165
*/
byte readInputs() {
  digitalWrite(RCK_INPUT, LOW);
  digitalWrite(RCK_INPUT, HIGH);
  //asm("nop\n nop\n");              //some delay

  byte switches = SPI.transfer(0); //get the switches states
  switchValues = switches;
  return switches;
}

void setup() {
  //Serial.begin(115200);//WORKS
  //Serial.begin(1000000);//Works
  Serial.begin(2000000);//Works

  //Initilize EEPROM if not initialized, else read from EEPROM
  byte initialized = EEPROM.read(0);
  //byte initialized = 0xFF;
  if (initialized > 0) {
    EEPROM.write(0, 0);
    for (int i = 0; i < 4; i++) {
      EEPROM.write(colorAddresses[i], channelValues[i]);
    }
    EEPROM.write(eepromOff, 0);
  }
  else {
    for (int i = 0; i < 4; i++) {
      channelValues[i] = EEPROM.read(colorAddresses[i]);
    }
    if (EEPROM.read(eepromOff) == 0x55) isOff = true;
    else isOff = false;
  }

  SPI.begin();

  //SPI.setDataMode(SPI_MODE0); // default - don't need
  SPI.setBitOrder(LSBFIRST); // MSBFIRST is default - comment out if determined as needed.

  pinMode(BUTTON, INPUT);
  pinMode(SW_MEM, INPUT);
  pinMode(SW_WR, INPUT);
  pinMode(SW_SERR, INPUT);

  pinMode(OUTPUT_ENABLE, OUTPUT);
  pinMode(RCK_INPUT, OUTPUT);
  pinMode(RCK_OUTPUT, OUTPUT);
  pinMode(RCK_TRANS, OUTPUT);

  digitalWrite(OUTPUT_ENABLE, HIGH);
  digitalWrite(RCK_INPUT, HIGH);
  digitalWrite(RCK_OUTPUT, HIGH);
  digitalWrite(RCK_TRANS, HIGH);

  FastLED.addLeds<WS2812B, RGB1_PIN, GRB>(leds, NUM_LEDS);  // GRB ordering is typical
  FastLED.addLeds<WS2812B, RGB2_PIN, GRB>(leds_rgb2, NUM_LEDS_RGB2);  // GRB ordering is typical

  setLedColors();
  delay(100);
}

void regularMode() {
  if (digitalRead(BUTTON) == HIGH) {
    buttonHigh();
  }
  else if (buttonTime != 0) {
    lastButtonActive = buttonTime;
    buttonTime = 0;
    buttonToggled = false;
  }

  byte inputs = readInputs();

  if (digitalRead(SW_WR) == HIGH && inputs != channelValues[color]) {
    channelValues[color] = inputs;
    // Could use a array and only write if the value actually changed.
    // Memory is only rated for 100k cycles.
    // Note: This function uses EEPROM.update() to perform the write, so does not rewrites the value if it didn't change.
    EEPROM.put(colorAddresses[color], inputs);
    setLedColors();
  }

  if (digitalRead(SW_MEM) == LOW)
  {
    setOutputValues(inputs);
  }
  else {
    setOutputValues(channelValues[color]);
  }

  if (isDebug) {
    for (int i = 0; i < 6; i++)
    {
      Serial.print("Output: ");
      printByte(outputs[i]);
      Serial.println("");
      Serial.print("Char: ");
      Serial.print(i);
      Serial.print(", is: ");
      Serial.println(outputChars[i]);
    }
    Serial.println("___________________");
  }
}

void offMode() {
  if (digitalRead(SW_WR) != HIGH) {
    isBlackout = false;
    isOff = false;
    EEPROM.put(eepromOff, 0);
    setLedColors();
    return;
  }
  if (outputChars[2] != 'F') {
    EEPROM.put(eepromOff, 0x55);
    setLedColors();
    setOutputValuesOff();
  }
}
void blackoutMode() {
  if (digitalRead(SW_SERR) != HIGH) {
    isBlackout = false;
    isCounter = false;
    setLedColors();
    return;
  }
  if (outputValues[0] != 0) {
    for (int i = 0; i < 6; i++) {
      outputValues[i] = 0x00;
      outputChars[i] = 0;
      setLedColors();
    }
  }
  delay(100);
}
void counterMode() {
  if (digitalRead(SW_MEM) != HIGH || digitalRead(SW_SERR) != HIGH) {
    //updateInterval = 100;
    isBlackout = false;
    isCounter = false;
    setLedColors();
    return;
  }
  if (digitalRead(BUTTON) == HIGH) {
    buttonHigh();
  }
  else if (buttonTime != 0) {
    lastButtonActive = buttonTime;
    buttonTime = 0;
    buttonToggled = false;
  }
  if (millis() - lastCount >= updateInterval) {
    if (counter == 255)
      counter = 0;
    else
      counter ++;
    setOutputValues(counter);
    lastCount = millis();
  }
}

void loop() {
  if (isOff) {
    offMode();
  } else if (isCounter) {
    counterMode();
  }
  else if (isBlackout) {
    blackoutMode();
  }
  else {
    regularMode();
  }
  long start = millis();
  while (millis() - start < 10) {
    //while (millis() - start < 50) {
    for (int i = 0; i < 6; i ++) {
      byte temp = outputValues[i];

      digitalWrite(OUTPUT_ENABLE, HIGH);
      digitalWrite(RCK_OUTPUT, LOW);
      digitalWrite(RCK_TRANS, LOW);

      SPI.transfer(outputs[i]);
      SPI.transfer(temp);

      digitalWrite(RCK_OUTPUT, HIGH);
      digitalWrite(RCK_TRANS, HIGH);
      digitalWrite(OUTPUT_ENABLE, LOW);
      if (i < 3 || i > 4) {
        //SuperRed 7-segment (or simple blue LED)
        delayMicroseconds(25);
      } else {
        delayMicroseconds(100);
      }
    }
    //delay(100)
  }
  digitalWrite(OUTPUT_ENABLE, HIGH);
  if (digitalRead(SW_SERR)) {
    if (isBlackout == false) {
      //Turn on the LEDS in accordance with this mode.
      isBlackout = true;
      blackoutMode();
      //Wait until next cycle to check the other ones? (Decided not to for some reason)
      //return;
    }
    if (digitalRead(SW_MEM)) isCounter = true;
    if (digitalRead(SW_WR)) isOff = true;
  }
}

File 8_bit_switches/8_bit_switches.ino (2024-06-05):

//Note this is obsolete and superseeded by rev-1!

//void ICACHE_RAM_ATTR buttonClick();
#include <EEPROM.h>
#include <FastLED.h>


// How many leds in your strip?
#define NUM_LEDS 5

// For led chips like WS2812, which have a data line, ground, and power, you just
// need to define DATA_PIN.  For led chipsets that are SPI based (four wires - data, clock,
// ground, and power), like the LPD8806 define both DATA_PIN and CLOCK_PIN
// Clock pin only needed for SPI based chipsets when not using hardware SPI
//#define uint8_t byte

#define BUTTON_PIN 2  // the number of the pushbutton pin
//Pin 3 could be used as interrupt
#define DATA_PIN 4 // Pin to connect resistor and RGB-strip to
#define WR_EN A4 // WriteEngage, active high
#define MEM_EN A5 // Will allow to write to serial; either memory or switch state (TOOD implement!)

//Will expand number of bits once I start soldering more ATMEGA328
byte switches [] = { 5, 6, 7, 8, 9, 10 , 12, 13}; //LSB => MSB
byte switchValues = 0b10000000;
byte lastWrittenToSerial = 0b00000000;

// Define the array of leds
CRGB leds[NUM_LEDS];

// Global Variables:
volatile byte color = 0;//r,g,b,NO color
byte colorAddresses[] = {1, 2, 3, 4};//Addresses for EEPROM/rgb; NONE
byte channelValues[] = {0b10000000, 0b10000000, 0b10000000, 0b00000000};//RGB; NONE

unsigned long button_time = 0;
unsigned long last_button_time = 0;

unsigned long led_write_time = 0;
volatile unsigned long last_led_write_time = 0;

int buttonState = 0;  // variable for reading the pushbutton status

void buttonClick() {
  button_time = millis();
  if (button_time - last_button_time > 250)
  {
    last_button_time = button_time;
    if (color == 3) {
      color = 0;
    } else {
      color += 1;
    }
    last_led_write_time = last_led_write_time - 500;
  }
}

long selectedColor() {
  switch (color)
  {
    case 0:
      return CRGB::Red;
    case 1:
      return CRGB::Green;
    case 2:
      return CRGB::Blue;
    case 3:
      return CRGB::Black;
  }
}

void readSwitches() {
  //Call this only if WR_EN is enabled
  byte temp = 0b00000000;
  for (unsigned i = 0; i < 8; i++) {
    bool isHigh = digitalRead(switches[i]) == HIGH;
    if (isHigh) {
      switch (i) {
        case 0:
          temp = temp | 0b00000001;
          break;
        case 1:
          temp = temp | 0b00000010;
          break;
        case 2:
          temp = temp | 0b00000100;
          break;
        case 3:
          temp = temp | 0b00001000;
          break;
        case 4:
          temp = temp | 0b00010000;
          break;
        case 5:
          temp = temp | 0b00100000;
          break;
        case 6:
          temp = temp | 0b01000000;
          break;
        case 7:
          temp = temp | 0b10000000;
          break;
      }
      delay(10);
    }
  }
  switchValues = temp;
}

void setLedColors() {
  leds[0] = selectedColor();
  leds[1] = CRGB(channelValues[0], 0, 0);
  leds[2] = CRGB(0, channelValues[1], 0);
  leds[3] = CRGB(0, 0, channelValues[2]);

  leds[4] = CRGB(channelValues[0], channelValues[1], channelValues[2]);
}
void writeToSerial() {
  String temp = "";
  if (digitalRead(MEM_EN) == HIGH) {
    if (lastWrittenToSerial == channelValues[color]) return;
    //Write from memory:
    temp = String(channelValues[color]);
    lastWrittenToSerial = channelValues[color];
  } else {
    //Write from switches:
    if (lastWrittenToSerial == switchValues) return;
    temp = String(switchValues);
    lastWrittenToSerial = switchValues;
  }
  temp += "\n";
  Serial.print(temp);
}

void setup() {
  Serial.begin(9600);

  //Initilize EEPROM if not initilized, else read from EEPROM
  byte initilized = EEPROM.read(0);
  if (initilized > 0) {
    EEPROM.write(0, 0);
    for (int i = 0; i < 4; i++) {
      EEPROM.write(colorAddresses[i], channelValues[i]);
    }
  }
  else {
    for (int i = 0; i < 4; i++) {
      channelValues[i] = EEPROM.read(colorAddresses[i]);
    }
  }

  //FastLED.addLeds<WS2812B, DATA_PIN, RGB>(leds, NUM_LEDS);  // GRB ordering is typical
  for (unsigned i = 0; i < 8; i++)  {
    pinMode (switches [i], INPUT);
  }
  pinMode(WR_EN, INPUT);
  pinMode(MEM_EN, INPUT);
  pinMode(BUTTON_PIN, INPUT_PULLUP);
  attachInterrupt(digitalPinToInterrupt(BUTTON_PIN), buttonClick, RISING);

  FastLED.addLeds<WS2812B, DATA_PIN, GRB>(leds, NUM_LEDS);  // GRB ordering is typical

  setLedColors();
  led_write_time = millis();
  FastLED.show();
  writeToSerial();
}

void loop() {
  if (digitalRead(WR_EN) == HIGH) {
    //if(false) {
    channelValues[color] = switchValues;
    EEPROM.put(colorAddresses[color], switchValues);
  }
  led_write_time = millis();
  if (led_write_time - last_led_write_time > 250)
  {
    setLedColors();
    FastLED.show();
    last_led_write_time = millis();
  }
  readSwitches();
  writeToSerial();
}

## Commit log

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2023-10-14 Broke it because needed to add bitwise operator to remember
    [8_bit_switches.ino]
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2023-12-03 Fixed the bug, also added loging
    [8_bit_switches.ino]
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2023-12-19 Fixed the serial communication to fit that of the hexadecimals
    [8_bit_switches.ino]
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2024-01-07 Added custom footprint and need to look at show to include it
    [Toggle_SW_Blue_R0.step, diagram_chart.kicad_sch]
2024-01-07 Added the required Transistors, need to add DC-plug, LEDs and 7-segments
    [diagram_chart.kicad_sch]
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2024-01-07 Experiments with flipflops
    [FlipFlop.kicad_pcb, FlipFlop.kicad_sch]
2024-01-07 Verified FlipFlop reset did not need a clock signal
    [FlipFlop.kicad_sch]
2024-01-13 Moved the KiCad things to it's own folder
    [FlipFlop.kicad_pcb, FlipFlop.kicad_sch, Toggle_SW_Blue_R0.step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]
2024-01-14 Restructured some and decided to go with 8mm char height
    [diagram_chart.kicad_sch]
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2024-01-28 Halfway done with wire-diagram, 90% of components have footprints
    [diagram_chart.kicad_sch]
2024-02-01 Connected all output-shift registers. Added Caps to ATMega Will need to fix the input-shift-register with switches. Also add Caps, then try to convert to PCB, then call night.
    [diagram_chart.kicad_sch]
2024-02-01 Added a lot of caps and wires Will try to convert to PCB Will tomorrow need to verrify
    [diagram_chart.kicad_sch]
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2024-02-01 Created PCB. Will need to map traces, and sizes tomorrow. Maybe order tomorrow or more probably tuesday next week.
    [diagram_chart.kicad_pcb, diagram_chart.kicad_sch]
2024-02-01 Changed from A3 to A4.
    Will make it easier to print PCB and check footprints before ordering.
    [diagram_chart.kicad_pcb]
2024-02-02 Made 14x14 cm. Positioned and alligned switches, displays and LEDs. 1oZ coppar makes me decide for 1mm width per AMP Meaning 0,2mm is enough for 200mA
    [diagram_chart.kicad_pcb, diagram_chart.kicad_sch]
2024-02-02 Centered the displays to middle Also grouped the entire section
    [diagram_chart.kicad_pcb]
2024-02-02 Added traces, and a lot of VIAS. Not certain about distances from pads, but expensive lessons are the best stucking ones.
    [diagram_chart.kicad_pcb]
2024-02-05 Fixed SPDT to correct sizes. Also flipped them so down is off. Added values of resistors, etc to silkscreen. Made the board 13x13 instead of 14x14. Centralized SPDT sw3, will after lunch center the r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
    [diagram_chart.kicad_pcb, diagram_chart.kicad_sch]
2024-02-05 Will need to recheck ignored violations tomorrow. DRC checker seems fine. Hole PTH to copper is fine at 0.35mm, not at 0,55. But YOLO
    [diagram_chart.kicad_pcb, diagram_chart.kicad_sch]
2024-02-06 Verified the footprint seems ok. Ran DRC checker several times.
    I can't claim to be certain of of anything, that would be jinxing.
    But will cross my fingers and order the PCB this afternoon.
    [diagram_chart.kicad_pcb, diagram_chart.kicad_sch]
2024-02-06 Removed holes from terminal-screws. Obs the gerber files here are not the ones ordered. I will upload zip from pcbway in next commit.
    [diagram_chart-B_Cu.gbr, diagram_chart-B_Mask.gbr, diagram_chart-B_Paste.gbr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]
2024-02-06 Ordered via JLCPCB Used GERBERS inside ZIP. Realized it is chinese new years.
    [diagram_chart-B_Cu.gbr, diagram_chart-B_Mask.gbr, diagram_chart-B_Paste.gbr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]
2024-02-28 Makeing a revision of the old design. Will focus on heavier GND but also SHORT data/clock and tied to SPI. Also makeing it 10x10cm since cheaper.
    [8_switch_rgb_pcb_revision_1.kicad_pcb, 8_switch_rgb_pcb_revision_1.kicad_sch]
2024-02-28 Added pad for serial incase SPI fails.
    Will move the ICs closer together to shorten the serial and clock lines.
    [8_switch_rgb_pcb_revision_1.kicad_pcb]
2024-02-29 Added 33 ohm series termination resistors. In series with all clock and dataoutputs
    [8_switch_rgb_pcb_revision_1.kicad_sch]
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2024-02-29 Added all components to board. But the amount of terrible track management is impossible without sleep. I had hopped to be done today, but the remaining tracks and DRC-check will take 2 hours, 4-8 if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
    The important data and clock need to be keept in acute memory.
    Data and clock includes OE and register-clocks.
    I tracked them at the verry begining, so it should be fine.
    Just need to be REALLY careful.
    [8_switch_rgb_pcb_revision_1.kicad_pcb, 8_switch_rgb_pcb_revision_1.kicad_sch]
2024-03-01 Made GND 1 mm, aswell as 5v. Will Maybe fill the entire plane with GND at the end.
    Depends how saddened the DRC will make me.
    [8_switch_rgb_pcb_revision_1.kicad_pcb]
2024-03-01 Connected all traces. Will now run DRC This is the last 2-layer board with more than 10 components I ever create.
    [8_switch_rgb_pcb_revision_1.kicad_pcb, 8_switch_rgb_pcb_revision_1.kicad_sch]
2024-03-01 Added 3d And moved dot marking the orintation of 7-seg to within footprint.
    [8_switch_rgb_pcb_revision_1.kicad_pcb]
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2024-03-01 Added the zip from pcbway. Will order both with ground fill and without
    [8_switch_rgb_pcb_revision_1-B_Cu.gbr, 8_switch_rgb_pcb_revision_1-B_Mask.gbr, 8_switch_rgb_pcb_revision_1-B_Paste.gbr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]
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2024-03-02 Added some PDFs Realized the distance between the data line and the gnd for the pulldown resistor for data in from the 74hc165 is way too small, but can't do nothing about that now. It is two differe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
    Still ugly 45+45 degree angle within 2mm
    [8_switch_rgb_pcb_revision_1.kicad_pcb]
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2024-03-02 Made everything thinner, will try even thinner. Maybe even 8x8 hole in middle.
    [More_HOLE.stl]
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2024-03-04 Made a working 3d. It costs roughly 5 USD each from jlc3dp
    [Holder 100mm-Body001Pocket001_SMALL_MATERIAL.stl, Holder 100mm-Body001Pocket001_SMALL_MATERIAL_v1.stl, Holder 100mm-Body001Sketch.stl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]
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2024-03-05 Made smaler version, but several larger. 2mm Walls was recommended at JLCPCB
    [2mm_no_edge.stl, 2mm_walls.stl, Holder 100mm.FCStd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]
2024-03-13 Created holders to support 12mm plywood. Also one to display the noicy 120mm rev_0
    [08mm_bottom.stl, 1mm_bottom_pads_for_button_and_mcu.stl, 2-7mm_pocket_hex_1mm_bottom.stl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]
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2024-03-16 Found out why JLC3DP complained Regarding wall thickness, it was the 0.5mm pockets. The Resistor leg bender, I ordered without sanding, will see how solid it becomes
    [7_seg_rev1_100mm_mounting_frame.FCStd, frame_thickness.stl]
2024-04-03 Made resistor value visible in silkscreen. Being the only major issue I discovered during assembly I call it done.
    Also included exports for gerber-files using plugin "GerbersToOrder"
    I could ofc have made 330 ohm current limiting resistors 220, and also
    removed the filters, and made the button location more spacey.
    But I need to finish good enough for now.
    [8_switch_rgb_pcb_revision_1-B_Cu.gbr, 8_switch_rgb_pcb_revision_1-B_Mask.gbr, 8_switch_rgb_pcb_revision_1-B_Silks.gbr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]
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2024-04-04 Added reference to the sketch for PCB_mcu_rev1. I realized after a short walk that it's better to continue tomorrow with the contents of the freecad readme. I will tomorrow also need to review the sk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
    Then ask for reviews to maybe clarify possible confusion or insanity of
    the repo.
    But I feel I then need to call quits on this project; only thing
    reminding is the fun/rewarding things of assembling, adding assembly instructions
    and gifting it/delivering to the end-user.
    But now food and sleep.
2024-04-05 Cleaned the cadfiles Also finished 80+% of the CAD readme. Need to eat, then finish the other readme, then finish this one I just started.
    [08mm_bottom.stl, 1mm_bottom_pads_for_button_and_mcu.stl, 2-7mm_pocket_hex_1mm_bottom.stl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]
2024-04-05 Fixed the things the todo told me to. Also fixed some spelling.
    [8_switch_rgb_rev_1_master_control.ino]
2024-04-19 Added links to video about assembling of stand. Also adding details about 3d-printed tools used in this assembly.
    [led_matrix_holder-BodyPad.stl, led_matrix_holder.FCStd]
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2024-06-05 Corrected a const that was volatile, also made useage of "volatile" consistent. Realized I lack basic C best-practices, examples: 1. Optimized useage of "volatile" 2. Naming conventions (mostly just 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
    [8_switch_rgb_rev_1_master_control.ino]
2024-06-05 Made the LED-strip be possible to mount reversed order
    [8_bit_switches.ino, 8_switch_rgb_rev_1_master_control.ino]
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
